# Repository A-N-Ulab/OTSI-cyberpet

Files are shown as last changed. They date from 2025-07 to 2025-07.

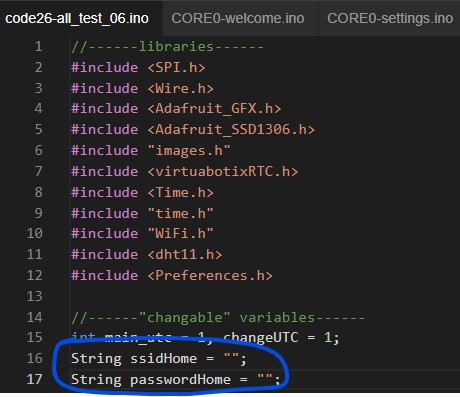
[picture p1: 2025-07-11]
instructions/change wifi.jpg

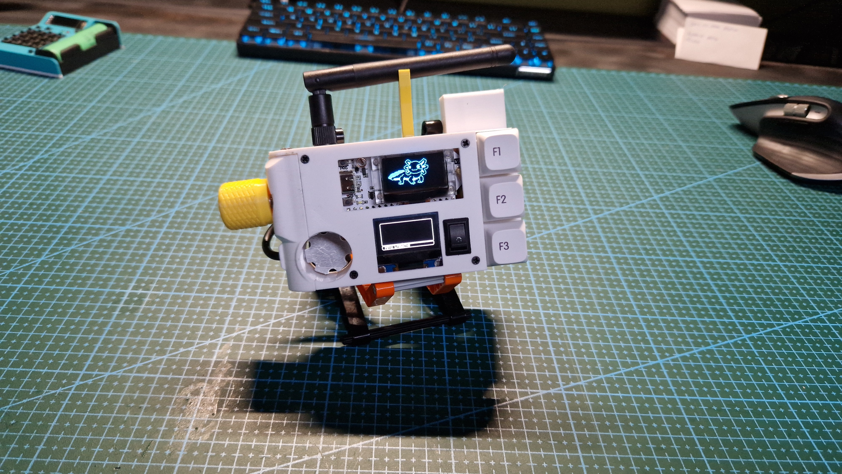
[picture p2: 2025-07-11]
photos/20240127_144444.jpg

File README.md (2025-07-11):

<p align="center">
  

</p>
<p align="center">
  
  
  
  
  
</p>

<p align="center">
  
  
  

</p>

**<p align="center">Info! This is a reupload of Otsi's repo bc of security stuff</p>**

# About this project
### Story
It all started when [cyberdeck cafe](https://cyberdeck.cafe/) announced a contest for cyberpet based on heltec development board. And fast forward 6 months my cyberpet is ALMOST done.

### Credits
Otsi's graphics are based on axolotl design made by [witch](https://dinopixel.com/pixel-art/purple-axolotl/17015)   
Main menu is based on a desing by [upirr](https://github.com/upiir/arduino_oled_menu)   
This project wouldn't be possible without awesome cyberdeck cafe's community. [Cyberdeck cafe website](https://cyberdeck.cafe/), [Cyberdeck cafe discord](https://discord.gg/cyberdeck-cafe-607459933784637460)

### Disclaimers 
* There are a lot of things that can and probably will change, to get latest cad files, code and instructions download lates [release](https://github.com/A-N-Ulab/OTSI-cyberpet/releases/latest)
* soldering otsi is not beginner friendly, have it in mind before you start this project

# Build your own
### Needed items
Detailed information about needed items is in the newest release in pdf called *__list of items needed__*
| Name | Quantity(pieces) | info |
| --- | --- | --- |
| heltec LoRa v3 | 1 | - |
| Mx switch | 3 | i'm using brown ones |
| Antena for lora | 1 | IPX to SMA cable and SMA antena |
| Keycap | 3 | - |
| 18650 battery cell | 1 | - |
| 18650 battery holder | 1 | 76x20x19mm |
| RTC DS1302 | 1 | - |
| CR2032 | 1 | - |
| DHT11 | 1 | temperature and humidity sensor |
| ec11 rotary encoder | 1 | rotary encoder with button |
| Rocker switch | 1 | cutoutsize of 13.5x9mm |
| photo resistor 5-10kohm | 1 | - |
| 3mm LED | 2 | one blue LED and one red LED |
| TP4056 | 1 | with USB C |
| push button | 1 | 6x6mm |
| USB C cable| 1 | USB A to USB C|
| 1W led | 1 | max heatsink diameter 20mm |
| I2C 0.96inch OLED | 1 | - |
| 10k resistor | 5 | - |
| M2 threaded inserts | 6 | - |
| M2x8mm screws | 6 | - |

### Case
Theoretically you could design your own case but I'm providing my case design. There are 5 stl's:  
* Antena holder - print without supports
* Knob - print without supports
* Cover - pritn with supports
* Two Main body files, one with holes for m2 threded inserts one with holes just for screws - both are print without supports    
Additionaly there are 2 files (.f3d and .step) that contain whole Otsi design

### Schematic and soldering
More accurate schematic is avaiable in latest release in pdf called *__schematic__*  
schematic image
Solder everything according to the schematic provided, for additional help in latest release there is a pdf file named *__photos__* that have, as name sugests, all the photos from my soldering process.

### Software
Before uploading otsi's code you are going to have
to change 2 variables:    
     
Set those two variables to WiFi network (ssid and password) that you always want to connect to, your *__home wifi__*     
After that you are ready to upload code to your heltec or from now your own Otsi cyberpet   

### Usage
To go to main many or chose any option press enoder's button, button number 3 is a return, everything else will be descibed on otsi itself.  
To charge Otsi use port on the top. To program Otsi use USB cable.  
NEVER PLUG IN OTSI TO USB WHEN POWER SWITCH IS TURNED ON

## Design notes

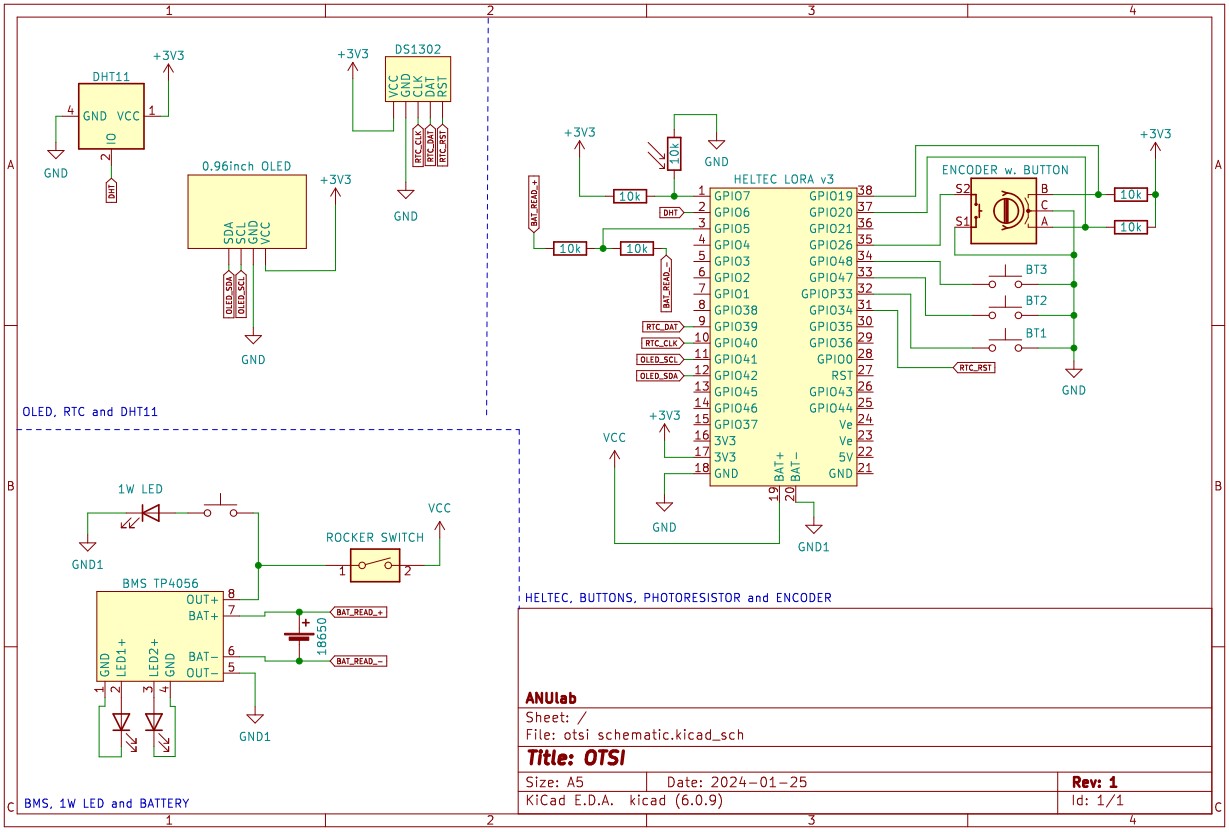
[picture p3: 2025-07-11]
instructions/schematic image .jpg

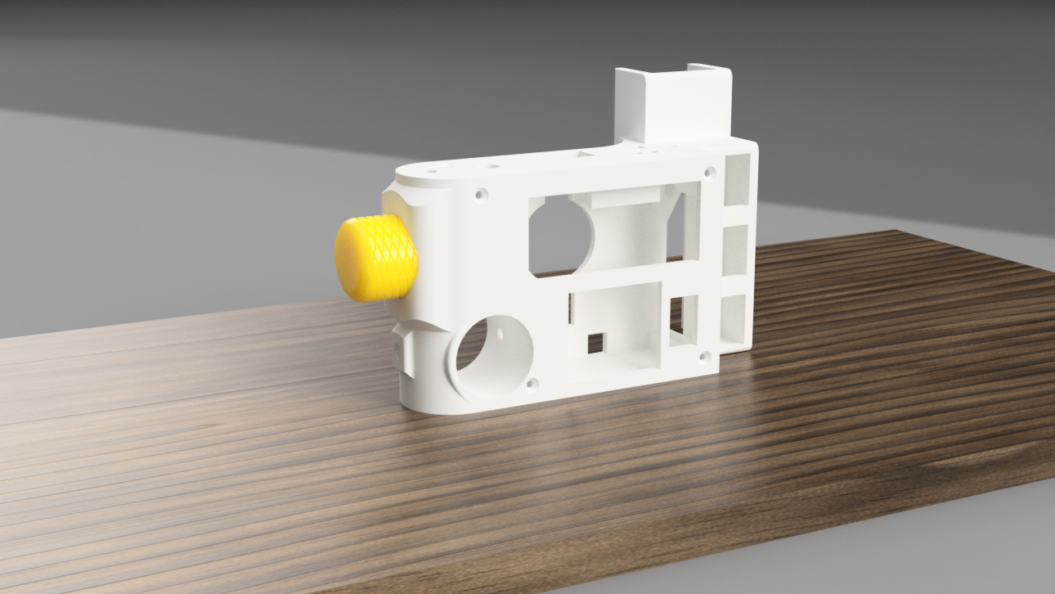
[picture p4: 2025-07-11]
photos/received_341719275412142.png

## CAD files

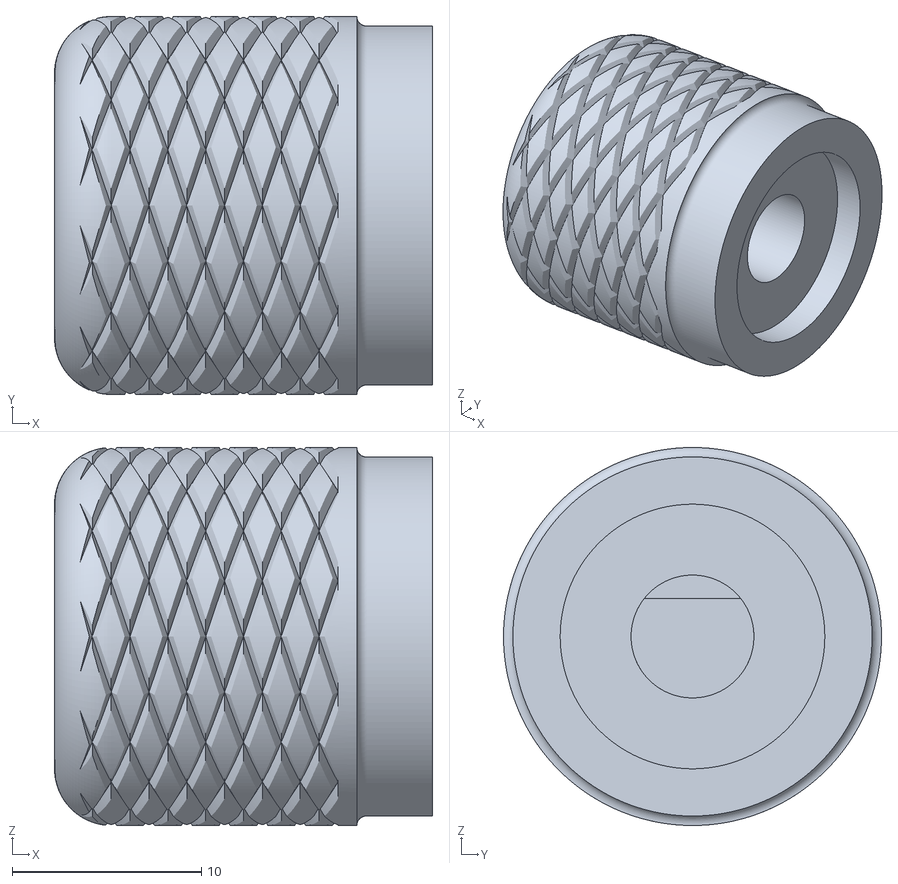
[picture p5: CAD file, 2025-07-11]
cad files/new cad files - Otsi rev2/knob v2.2.stl
20.0 x 20.0 x 20.0

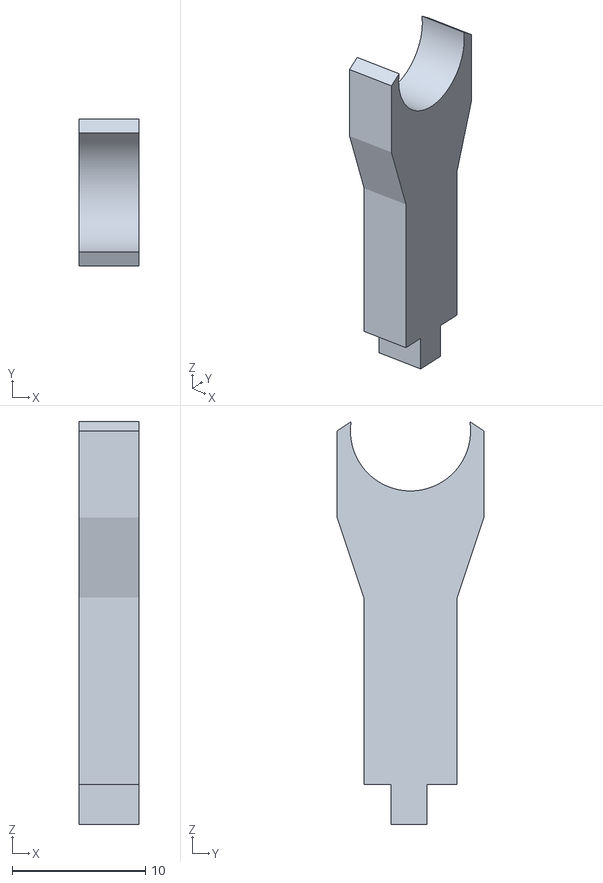
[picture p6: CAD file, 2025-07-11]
cad files/new cad files - Otsi rev2/antena holder v1.3.stl
4.50 x 11.0 x 30.2

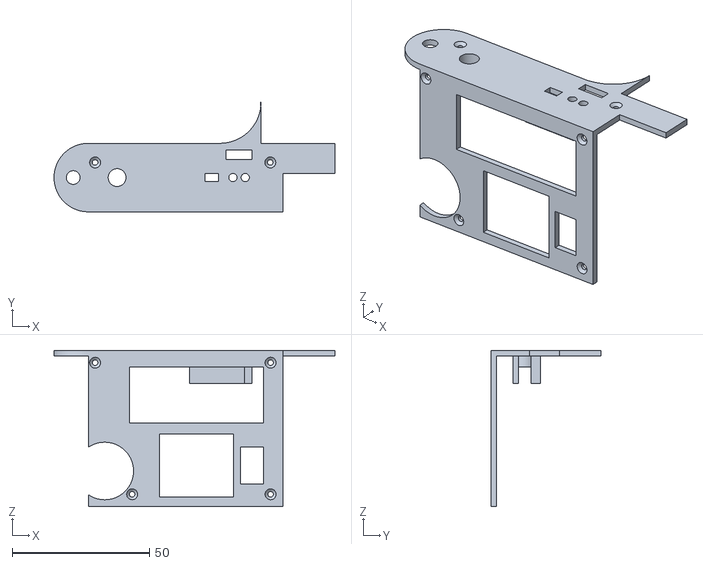
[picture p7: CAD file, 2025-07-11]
cad files/new cad files - Otsi rev2/cover v2.2.stl
102.5 x 40.0 x 57.0

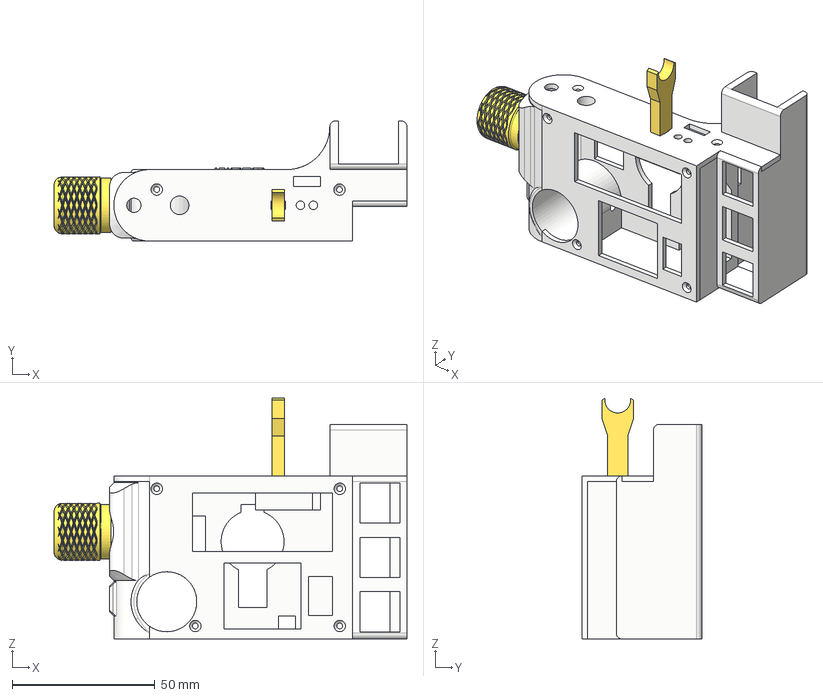
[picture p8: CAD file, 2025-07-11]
cad files/new cad files - Otsi rev2/otsi 25012024.step
123.4 x 42.0 x 84.2 mm
knob
cover
antena holder

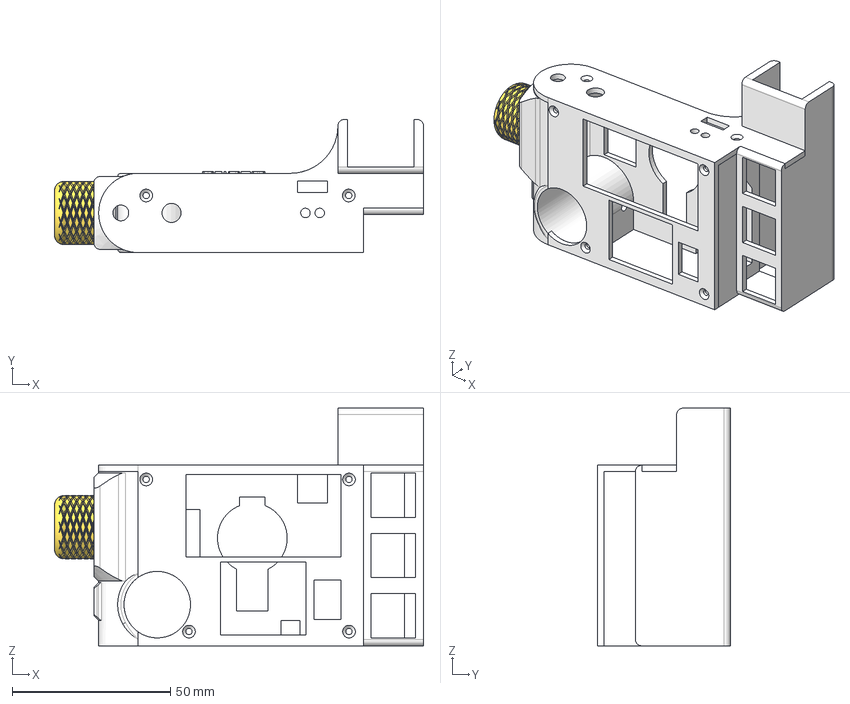
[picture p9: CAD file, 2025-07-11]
cad files/new cad files - Otsi rev2/otsi 13012024.step
116.4 x 42.0 x 75.0 mm
knob

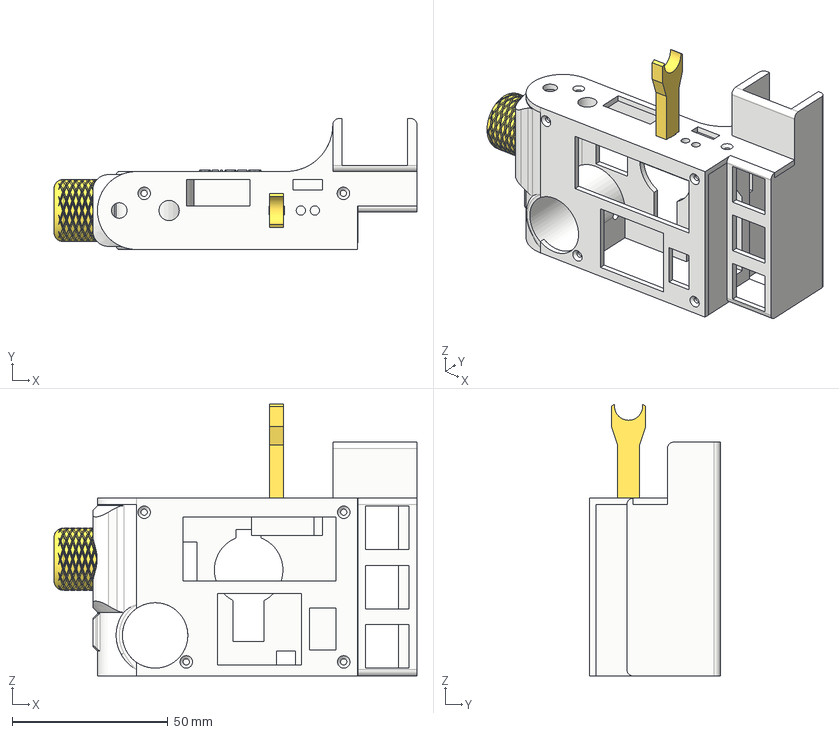
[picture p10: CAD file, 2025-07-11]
cad files/new cad files - Otsi rev2/otsi 16012024.step
116.4 x 42.0 x 87.2 mm
knob
cover
antena holder

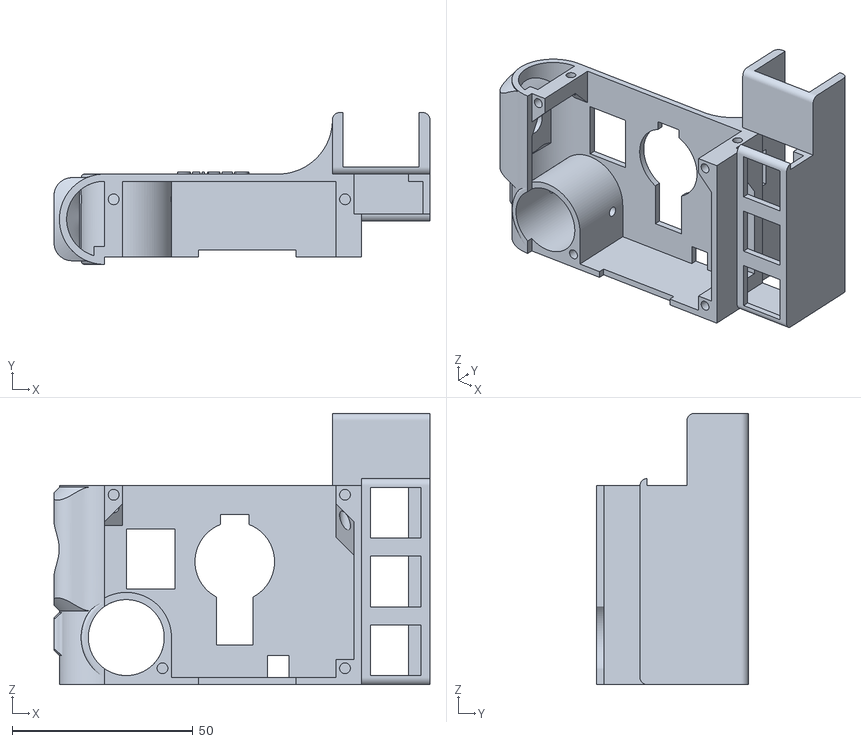
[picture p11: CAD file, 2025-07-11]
cad files/new cad files - Otsi rev2/body v2.2.stl
104.0 x 42.0 x 75.0

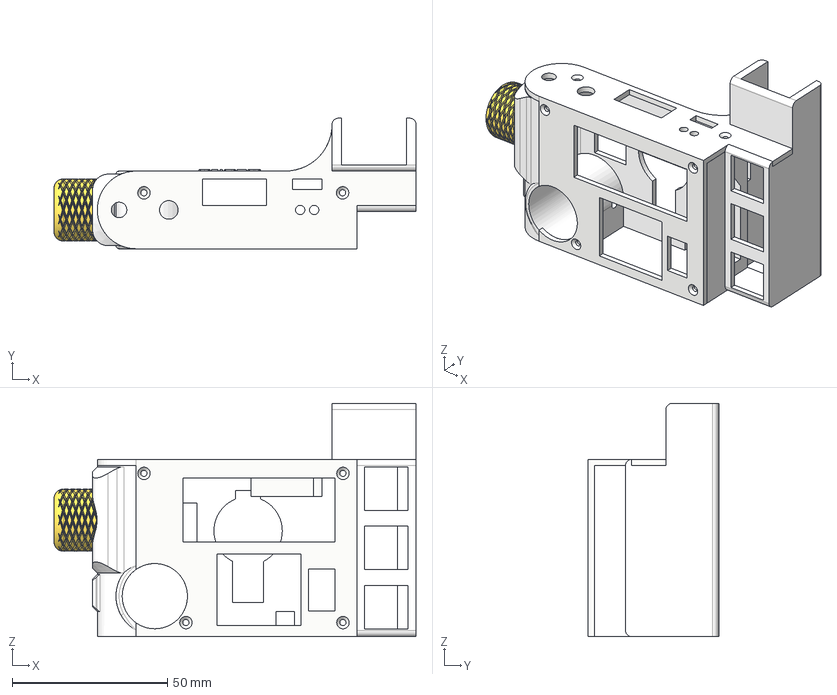
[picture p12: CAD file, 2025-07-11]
cad files/new cad files - Otsi rev2/otsi 15012024.step
116.4 x 42.0 x 75.0 mm
knob
cover

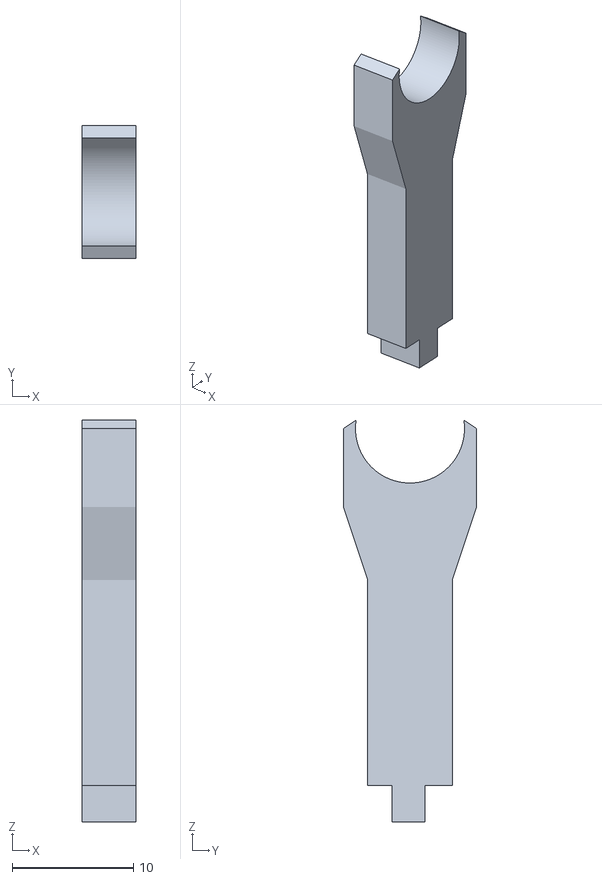
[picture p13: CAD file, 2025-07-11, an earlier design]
cad files/new cad files - Otsi rev2/antena holder v1.1.stl
4.50 x 11.0 x 33.2

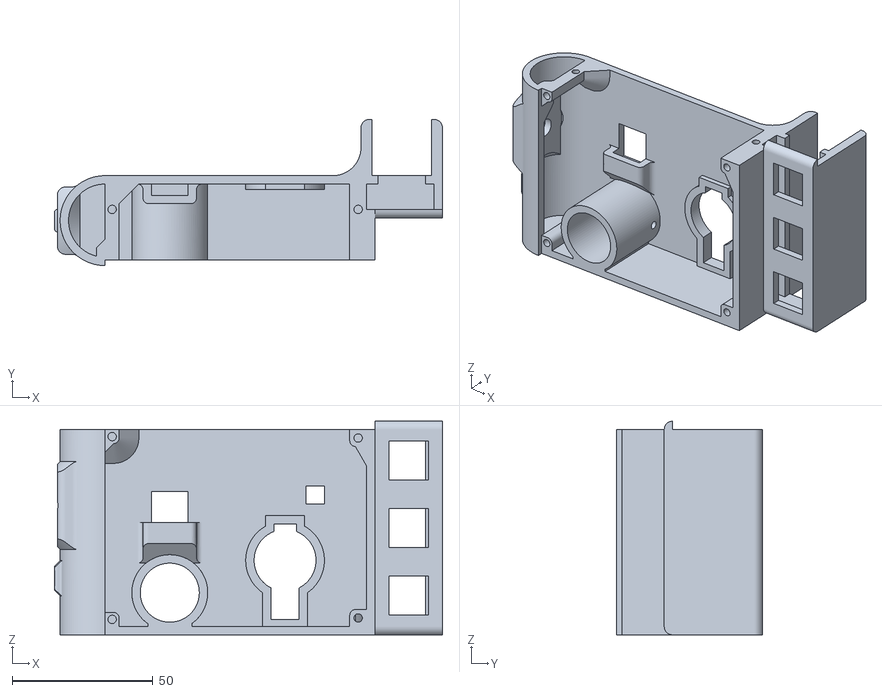
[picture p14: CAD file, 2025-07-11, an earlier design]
cad files/old cad files - Otsi rev1/body v2.stl
138.0 x 52.0 x 76.0

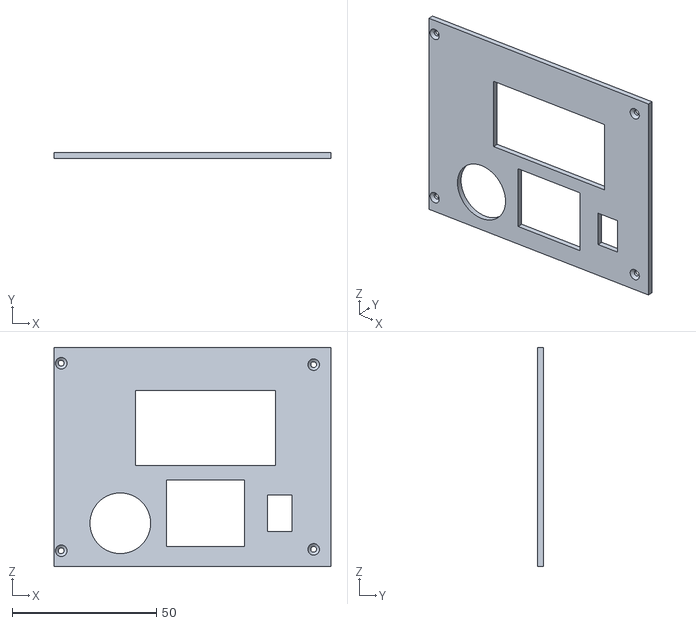
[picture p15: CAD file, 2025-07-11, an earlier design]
cad files/old cad files - Otsi rev1/cover v1.stl
96.0 x 2.00 x 76.0

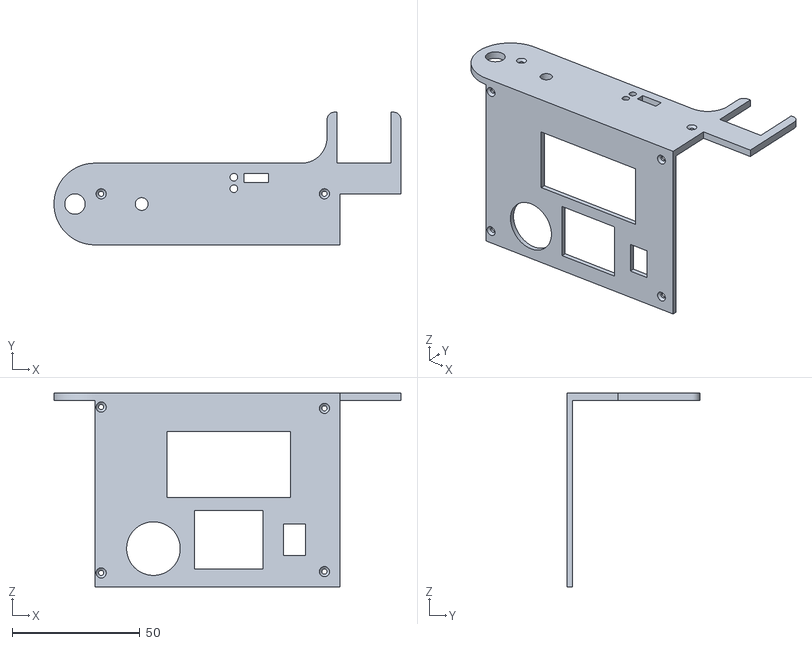
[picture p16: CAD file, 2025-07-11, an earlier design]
cad files/old cad files - Otsi rev1/cover v2.stl
136.0 x 52.0 x 76.0

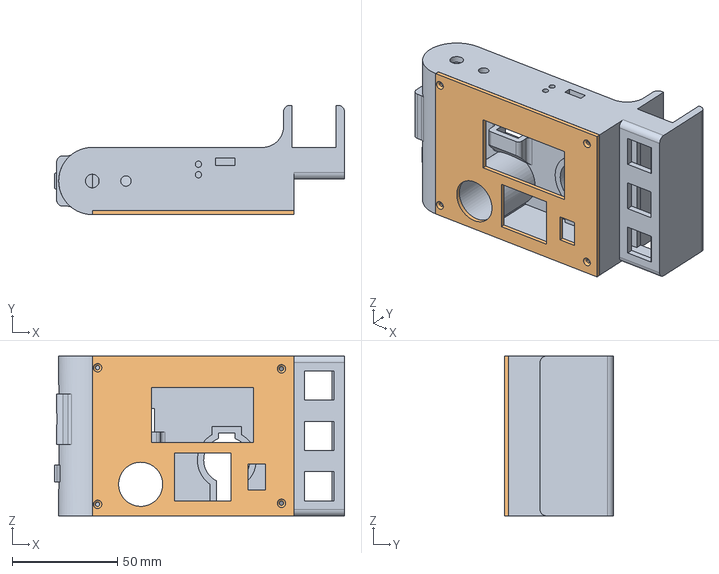
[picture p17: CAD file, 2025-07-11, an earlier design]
cad files/old cad files - Otsi rev1/otsi 10012024.step
138.0 x 52.0 x 76.0 mm

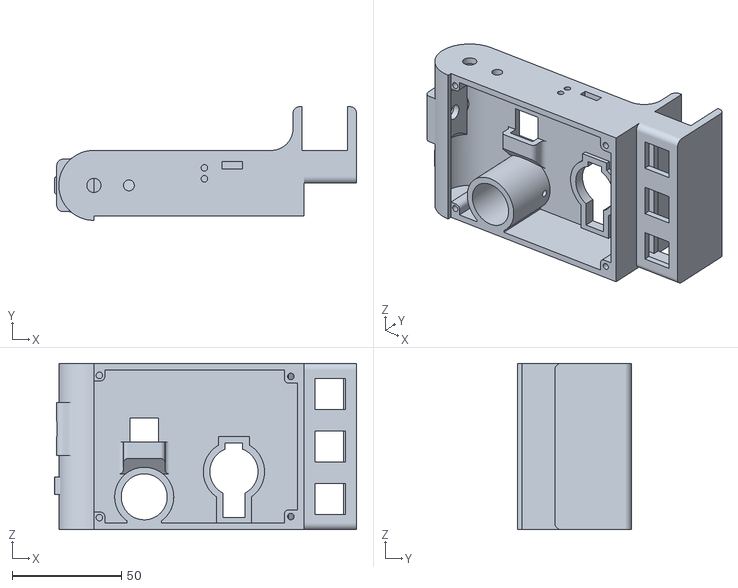
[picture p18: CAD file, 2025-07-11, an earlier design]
cad files/old cad files - Otsi rev1/body v1.stl
138.0 x 52.0 x 76.0

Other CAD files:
cad files/new cad files - Otsi rev2/otsi 24012024.step
cad files/new cad files - Otsi rev2/body v2.3 - inserts.stl
cad files/new cad files - Otsi rev2/body v2.3 - no inserts.stl
cad files/new cad files - Otsi rev2/body v1.stl
cad files/new cad files - Otsi rev2/antena holder v1.2.stl
cad files/new cad files - Otsi rev2/antena holder v1.stl
cad files/new cad files - Otsi rev2/body v2.1.stl
cad files/new cad files - Otsi rev2/body v2.stl
cad files/new cad files - Otsi rev2/cover v1.stl
cad files/new cad files - Otsi rev2/cover v2.1.stl
cad files/new cad files - Otsi rev2/cover v2.stl
cad files/new cad files - Otsi rev2/knob v1.1.stl
cad files/new cad files - Otsi rev2/knob v1.stl
cad files/new cad files - Otsi rev2/knob v2.1.stl
cad files/new cad files - Otsi rev2/knob v2.stl
cad files/new cad files - Otsi rev2/otsi 13012024.f3d
cad files/new cad files - Otsi rev2/otsi 15012024.f3d
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

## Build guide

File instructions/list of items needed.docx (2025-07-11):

NAME | QUANTITY (pieces) | REFERENCE LINK | REFERENCE IMAGE

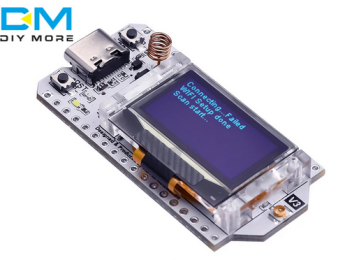
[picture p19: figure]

Heltec LoRa v3 | 1 | https://pl.aliexpress.com/item/1005004993408849.html

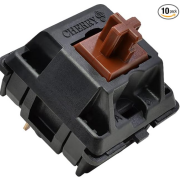
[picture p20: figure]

Mx switch (I’m using brown ones) | 3 | pack of 10: https://www.amazon.com/Original-Cherry-Switches-Mechanical-Keyboard/dp/B09J3GR5WD?th=1

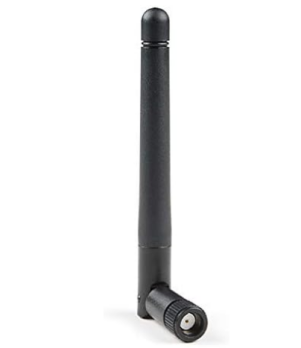
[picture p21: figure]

Antena and cable for LoRa REMEMBER TO ORDER THE RIGHT FREQUENCY FOR YOUR LORA | 1 | https://www.amazon.com/915MHz-LoRa-Antenna-RP-SMA-Wave/dp/B07HZ3BSHM/

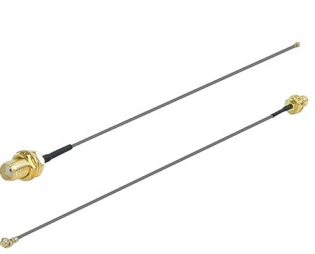
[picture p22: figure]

| 1 | Pack of 2: https://www.amazon.com/Proxicast-Low-Loss-Coaxial-Bluetooth-Antennas/dp/B09GJGNPQX/

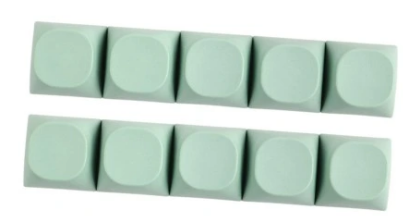
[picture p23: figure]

Keycap Best with numbers from 1 to 3 | 3 | https://www.amazon.com/SparkFun-Electronics-Cherry-MX-Keycap/dp/B082TMSLNQ/

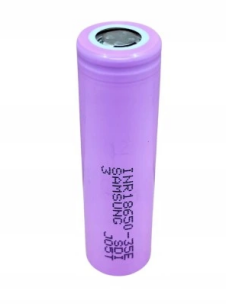
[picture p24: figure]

18650 battery cell | 1 | -

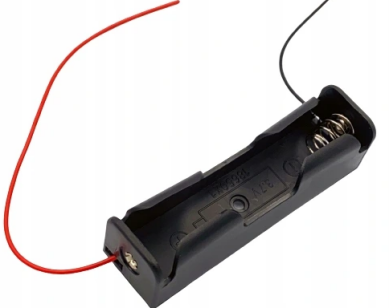
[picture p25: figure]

18650 battery holder | 1 | Pack of 10: https://www.amazon.com/DIANN-10pcs-Battery-Holder-Single/dp/B0BJV7SK5D/

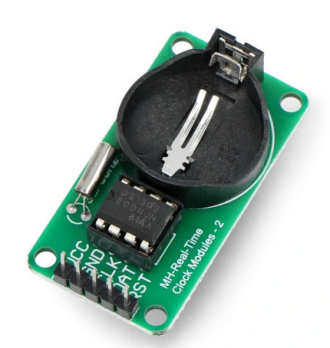
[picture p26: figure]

RTC DS1302 | 1 | https://www.amazon.com/RedTagCanada-DS1302-Module-Real-Time-Arduino/dp/B0CQYC3WJH/

DISCLAIMER:

Links are only for reference and some of them lead to e.g. pack of 20, the real quantity is in a column called the same. If there is quantity of 3 it means that you need 3 pieces e.g. 3 MX switches

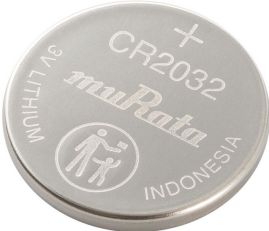
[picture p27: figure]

CR2032 | 1 | https://www.amazon.com/Duracell-Lithium-Battery-Lasting-Count/dp/B07G7KRQQ5/

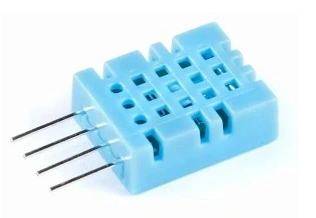
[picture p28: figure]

DHT11 temperature and humidity sensor | 1 | https://www.amazon.com/Micro-Traders-16x12-6x6mm-Temperature-Microcontrollers/dp/B0CMSTP1HS/

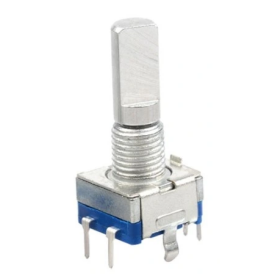
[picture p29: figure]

ec11 rotary encoder with button | 1 | https://www.amazon.com/Bolsen-Rotary-Encoder-Digital-Potentiometer/dp/B07HQD627T/

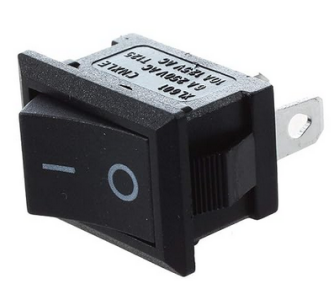
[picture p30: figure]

Rocker switch with cutout size of 13.5x9mm | 1 | https://www.amazon.com/Envistia-Mall-Rocker-Switch-125VAC/dp/B07QFN5Y9K/

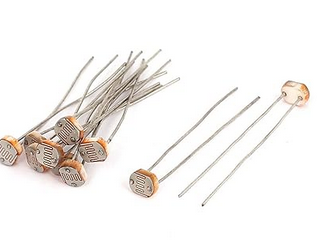
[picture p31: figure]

Photo resistor 5-10kOhm | 1 | https://www.amazon.com/a15071300ux0102-Resistor-Light-Dependent-Photoresistor-Optoresistor/dp/B00Q6ZIK1O

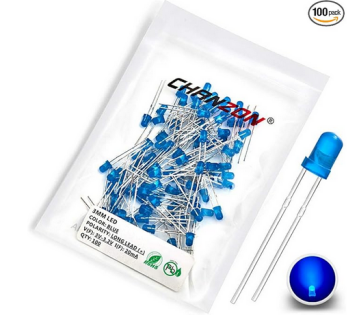
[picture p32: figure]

3mm led | 2 (1 red and 1 blue) | Red, pack of 100: https://www.amazon.com/Diffused-Lighting-Electronics-Components-Emitting/dp/B01C3W6NPS/ Blue, pack of 100: https://www.amazon.com/Diffused-Lighting-Electronics-Components-Emitting/dp/B01C3ZZT6O/

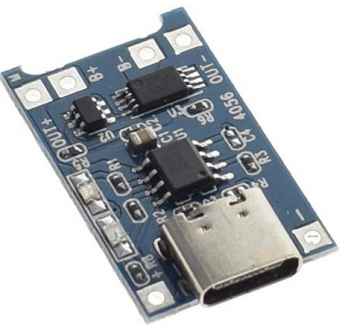
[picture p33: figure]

TP4056 | 1 | Pack of 3: https://www.amazon.com/HiLetgo-Lithium-Charging-Protection-Functions/dp/B07PKND8KG/

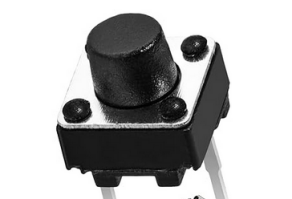
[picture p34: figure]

6x6mm push button | 1 | Pack of 20: https://www.amazon.com/Momentary-Terminal-Pushbutton-Breadboard-Electronic/dp/B09R3ZPWJ7/

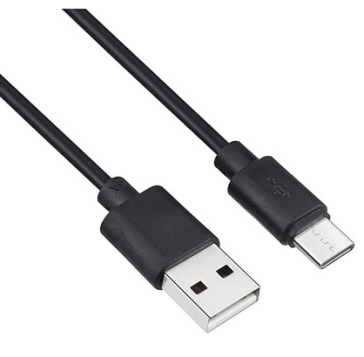
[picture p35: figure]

USB C cable (nothing too fancy, you are gonna cut it anyway) | 1 | https://www.amazon.com/PowerHOOD-Charging-Compatible-Ingenico-MOB55BBBAB-128/dp/B0C8W41D6S/

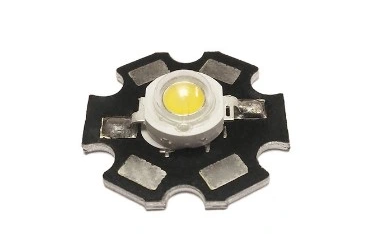
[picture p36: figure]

1W/3W led with max diameter of heatsink: 20mm | 1 | https://www.amazon.com/Light-Beads-Bright-Floodlight-5W-Warm/dp/B097S1RG9G/

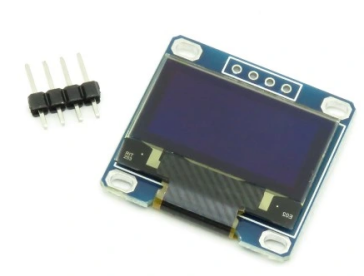
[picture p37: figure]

I2C 0.96 inch OLED display | 1 | Pack of 5: https://www.amazon.com/Hosyond-Display-Self-Luminous-Compatible-Raspberry/dp/B09C5K91H7/

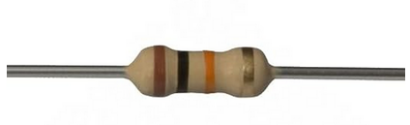
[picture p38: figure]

10k resistor | 5 | Pack of 100: https://www.amazon.com/Projects-100EP51210K0-10k-Resistors-Pack/dp/B0185FIOTA

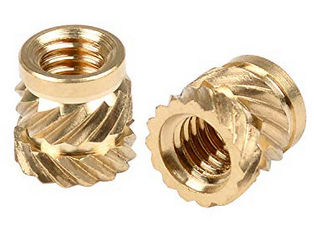
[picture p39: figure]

M2 Threaded inserts | 6 | Pack of 100: https://www.amazon.com/M2x4-0mm-OD3-6mm-Staking-Threaded-Inserts/dp/B08T7NDPQC
M2x5mm screws | 6 | Pack of 10: https://www.amazon.com/Deal4GO-10-Pack-Replacement-Phillips-Nickel/dp/B0B3751BM1/

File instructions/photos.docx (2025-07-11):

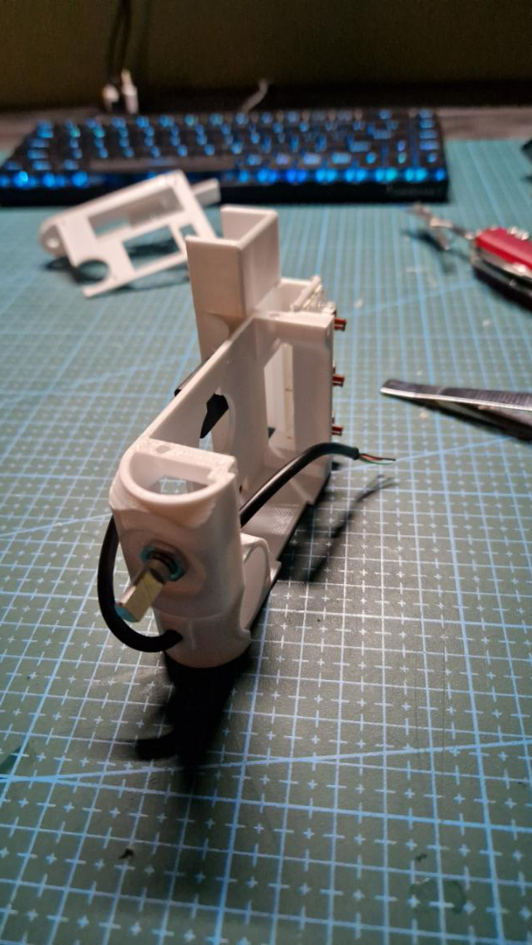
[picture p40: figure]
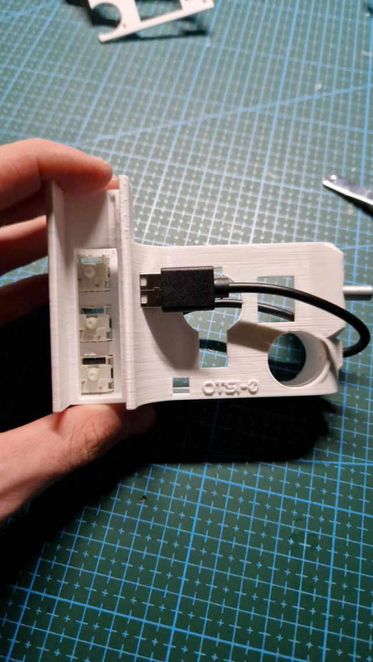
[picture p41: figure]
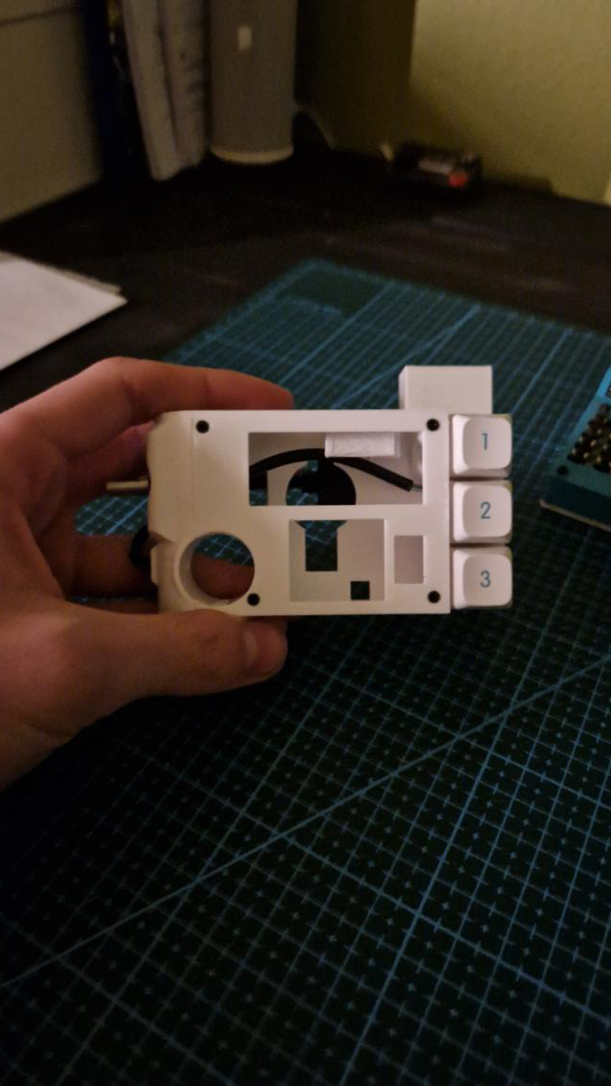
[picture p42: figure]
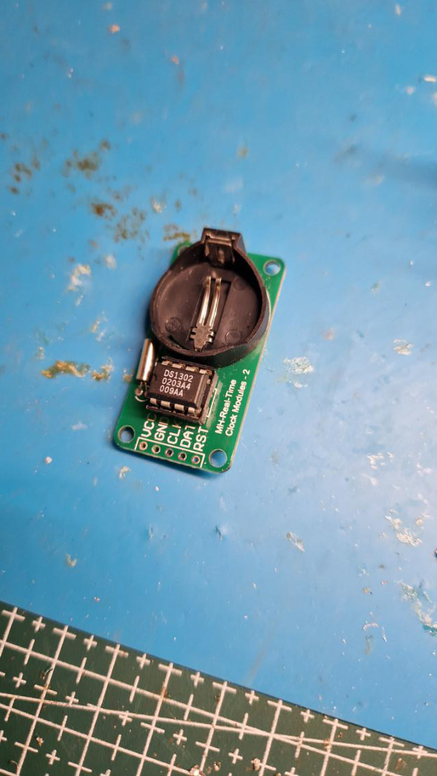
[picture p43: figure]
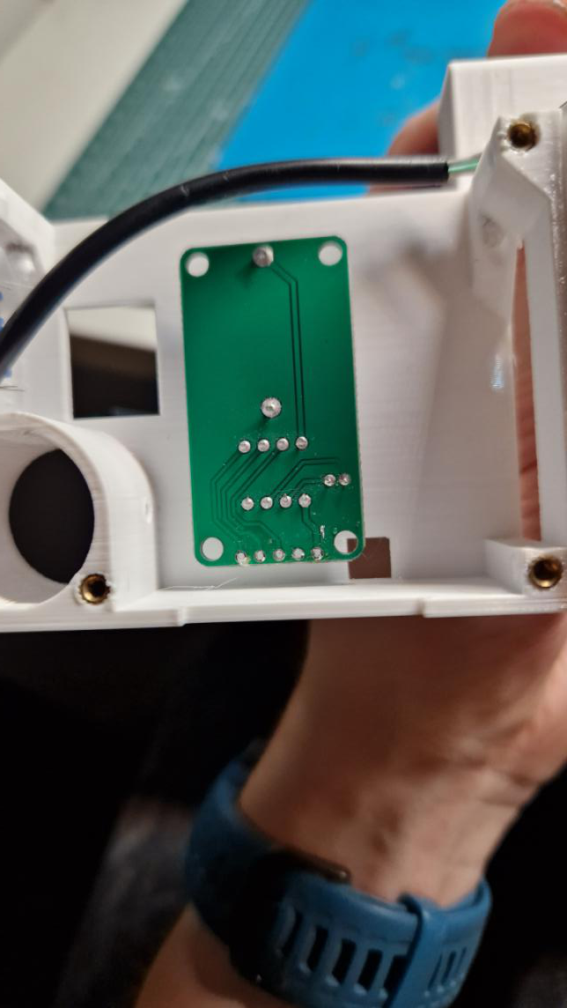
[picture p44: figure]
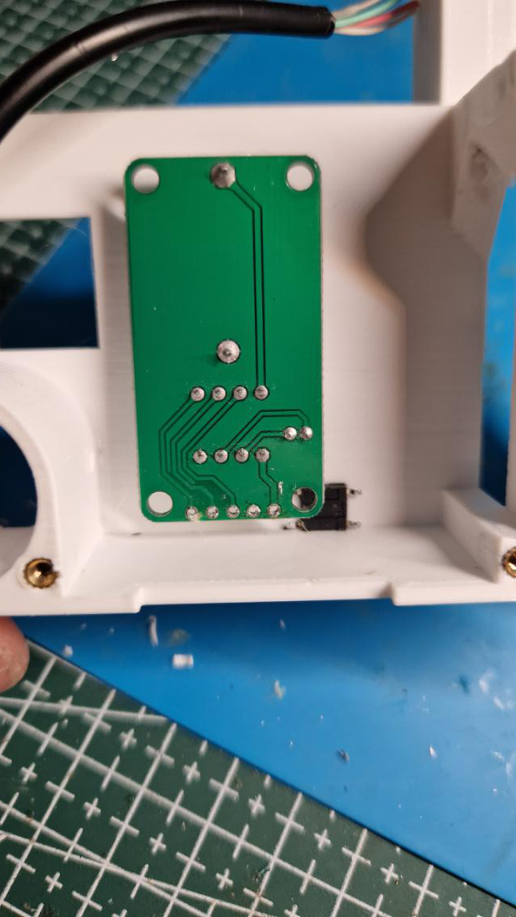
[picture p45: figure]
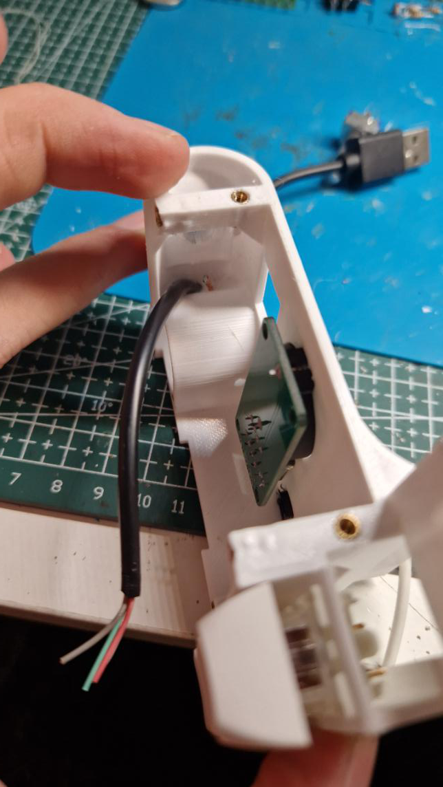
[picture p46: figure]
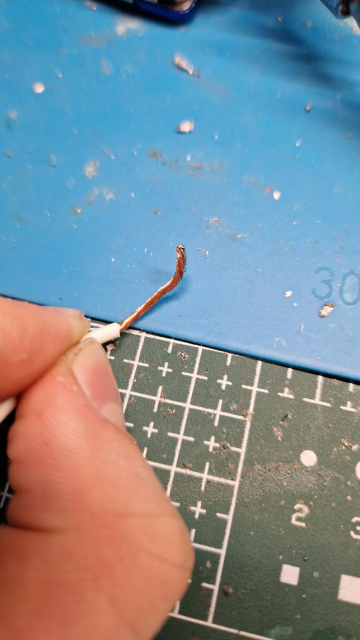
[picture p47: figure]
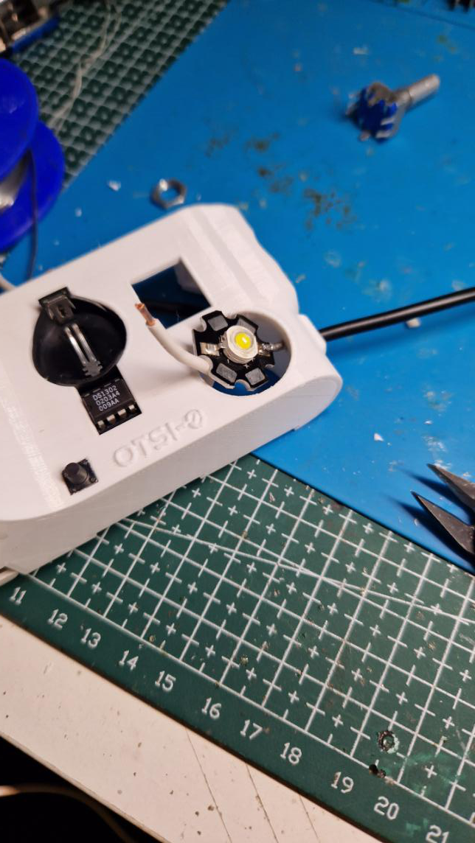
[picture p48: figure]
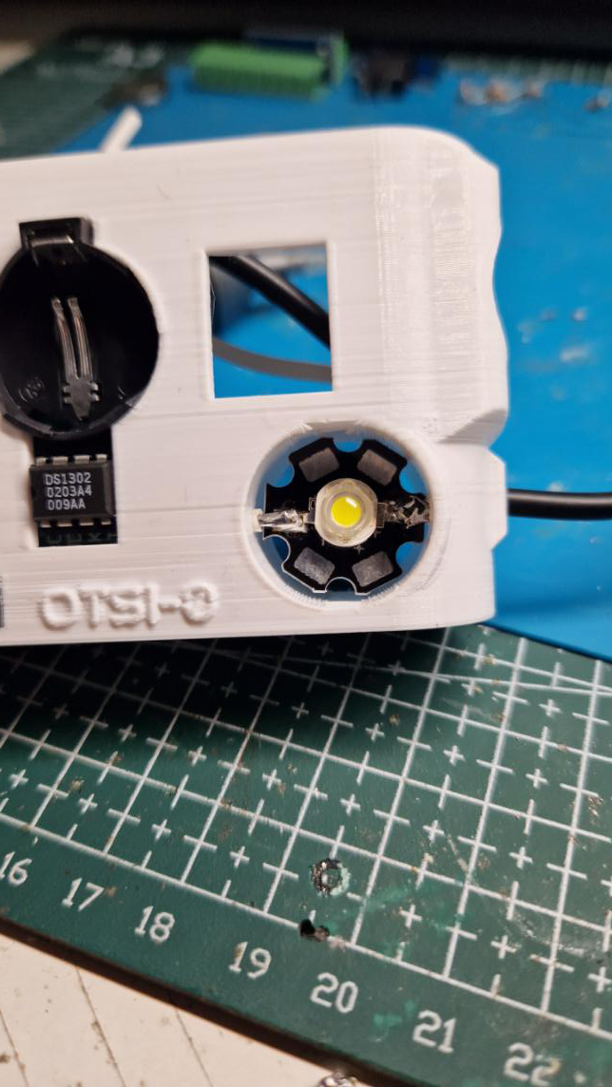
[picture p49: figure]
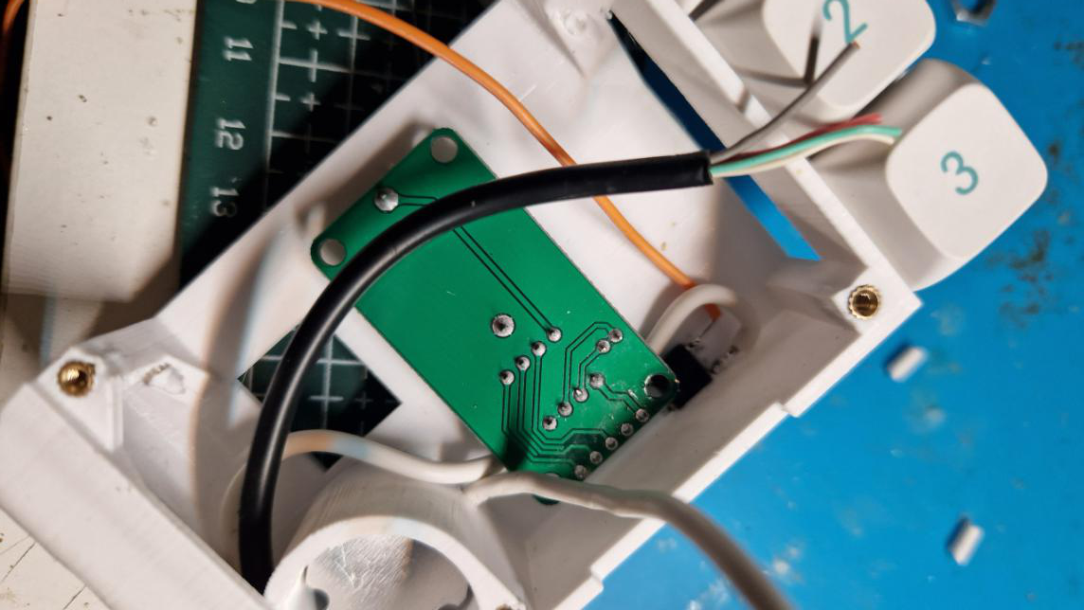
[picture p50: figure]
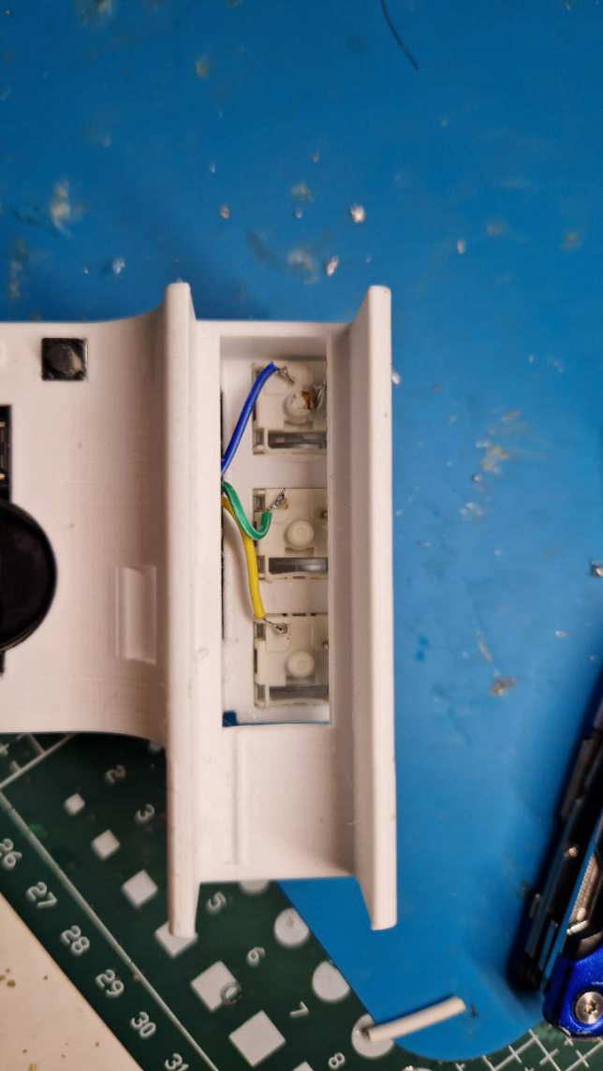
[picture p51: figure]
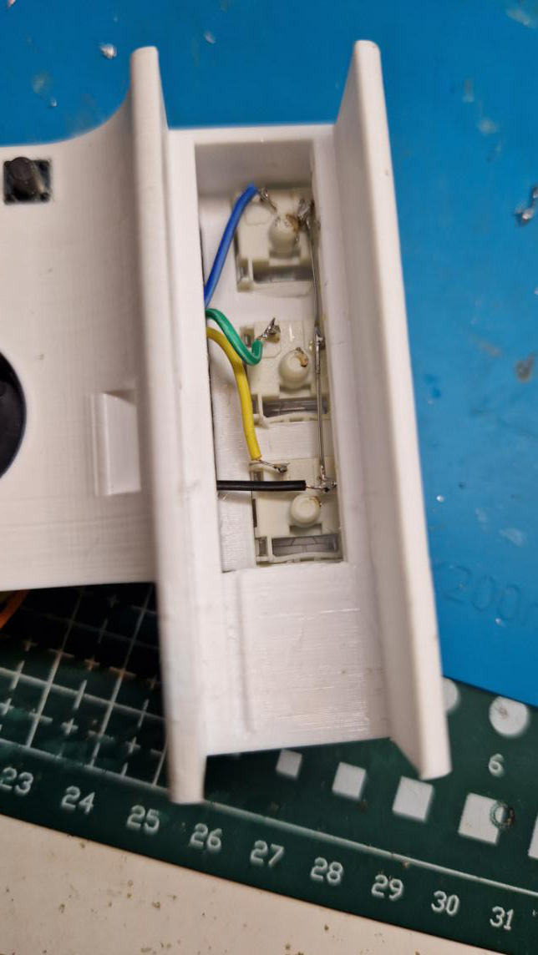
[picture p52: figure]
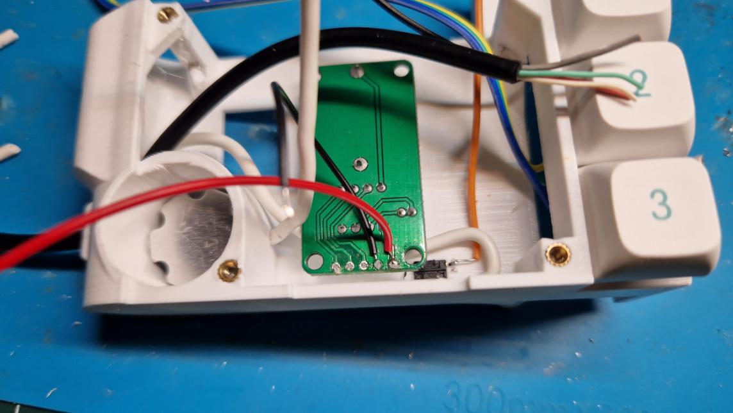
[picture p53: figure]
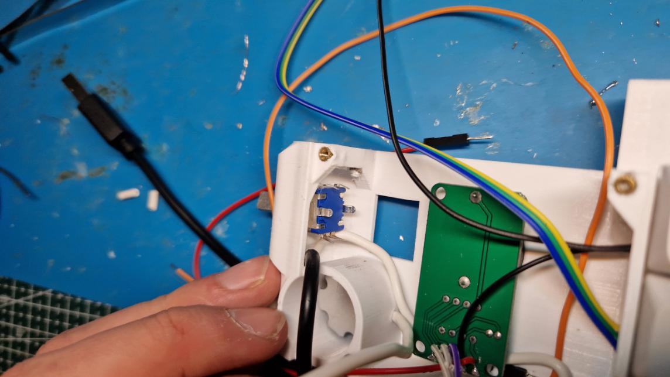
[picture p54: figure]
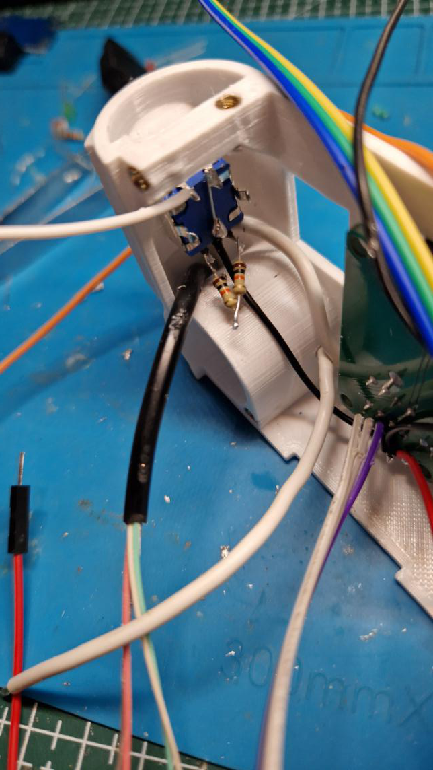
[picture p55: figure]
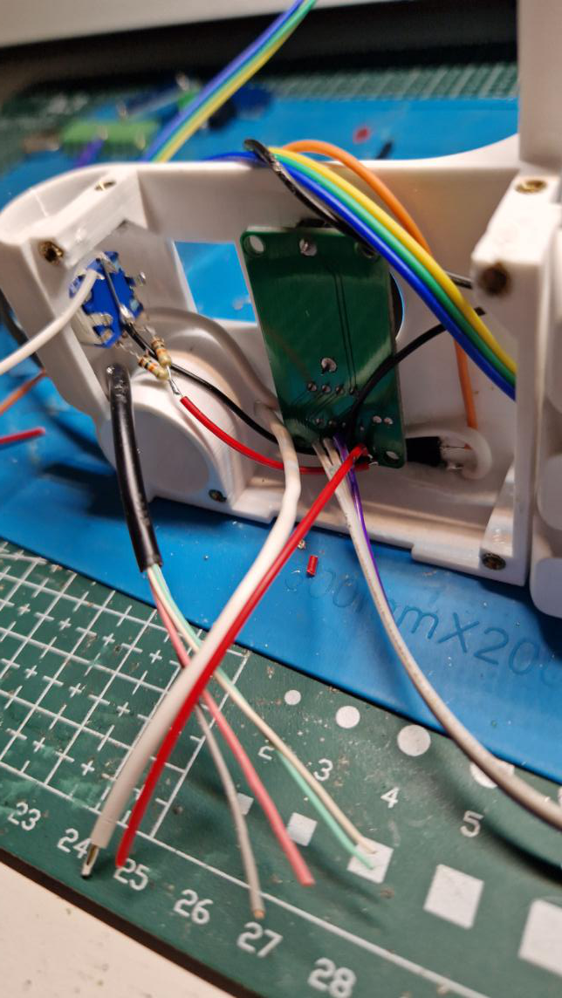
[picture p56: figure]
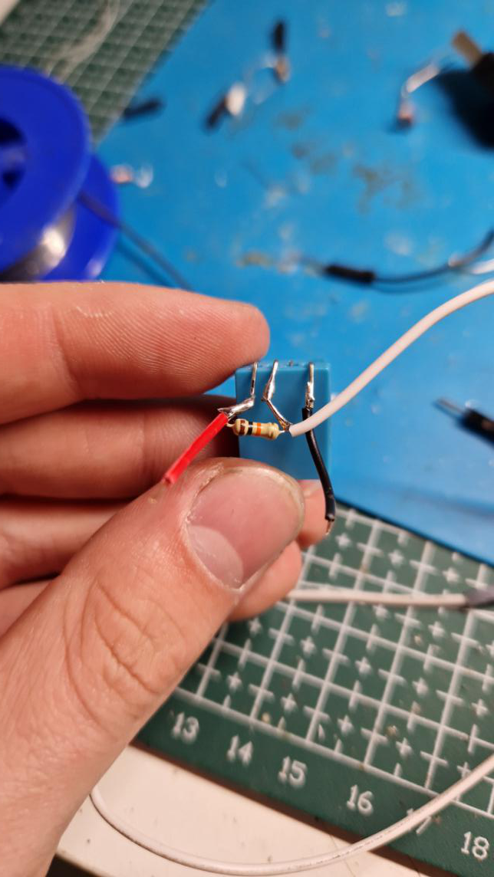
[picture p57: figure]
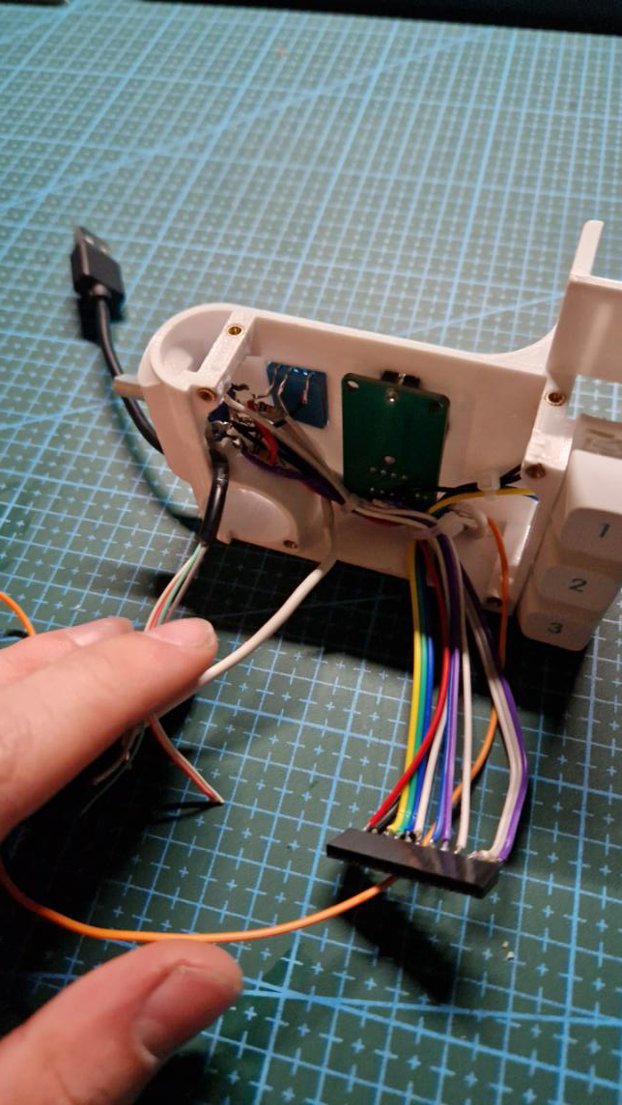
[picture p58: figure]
20231230_151600-cut

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
- cathode

- cathode

+ anode

34

33

32

37

36

35

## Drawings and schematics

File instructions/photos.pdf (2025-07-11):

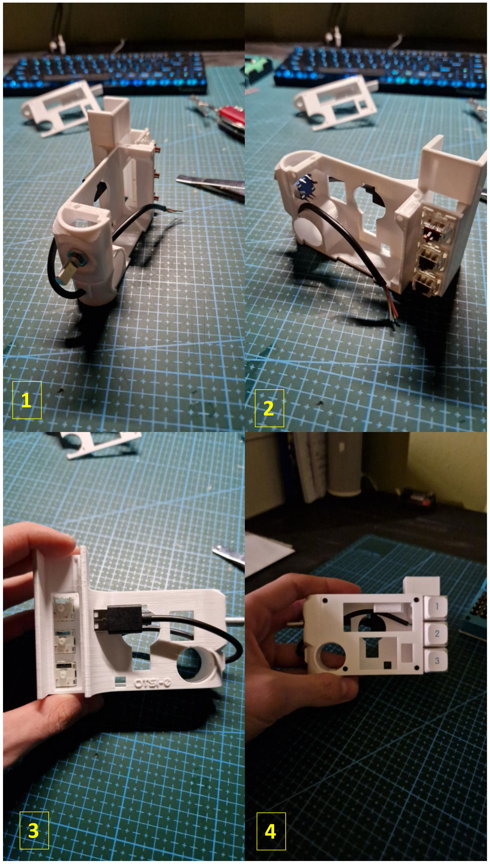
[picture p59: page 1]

1 2

3 4

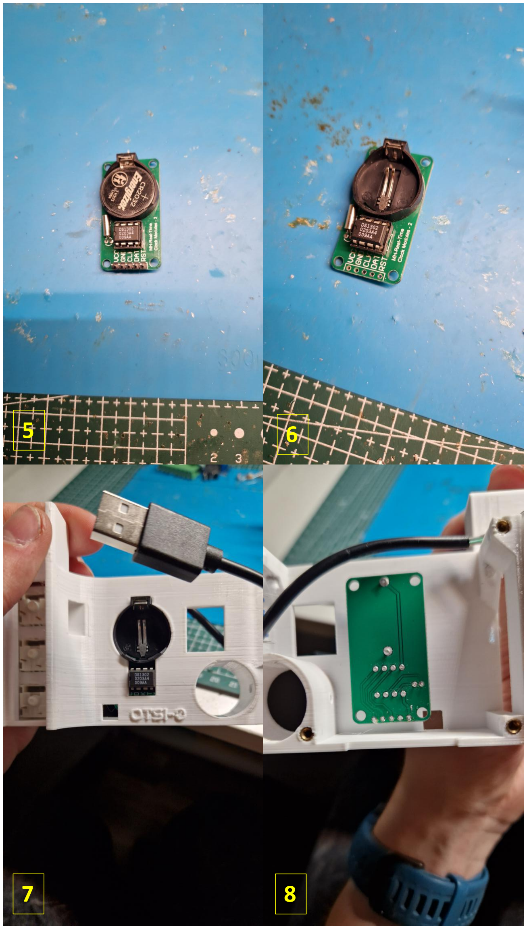
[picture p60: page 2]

5 6

7 8

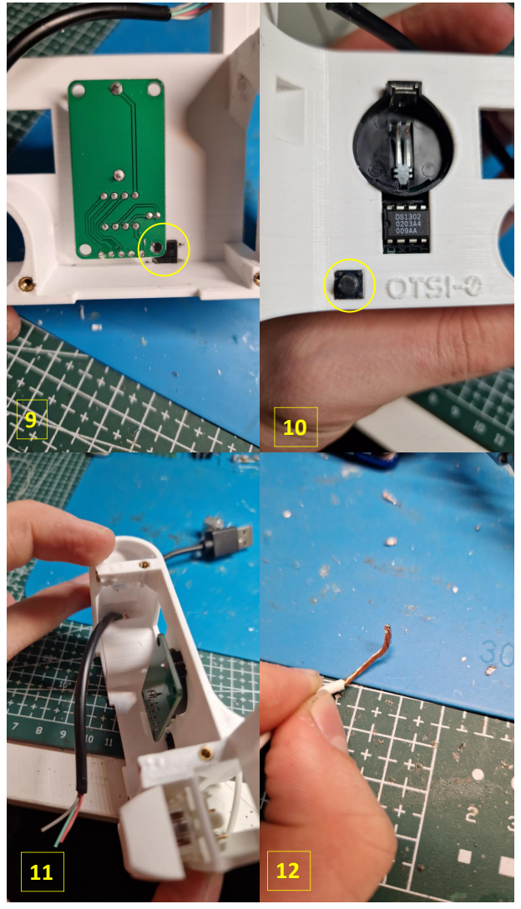
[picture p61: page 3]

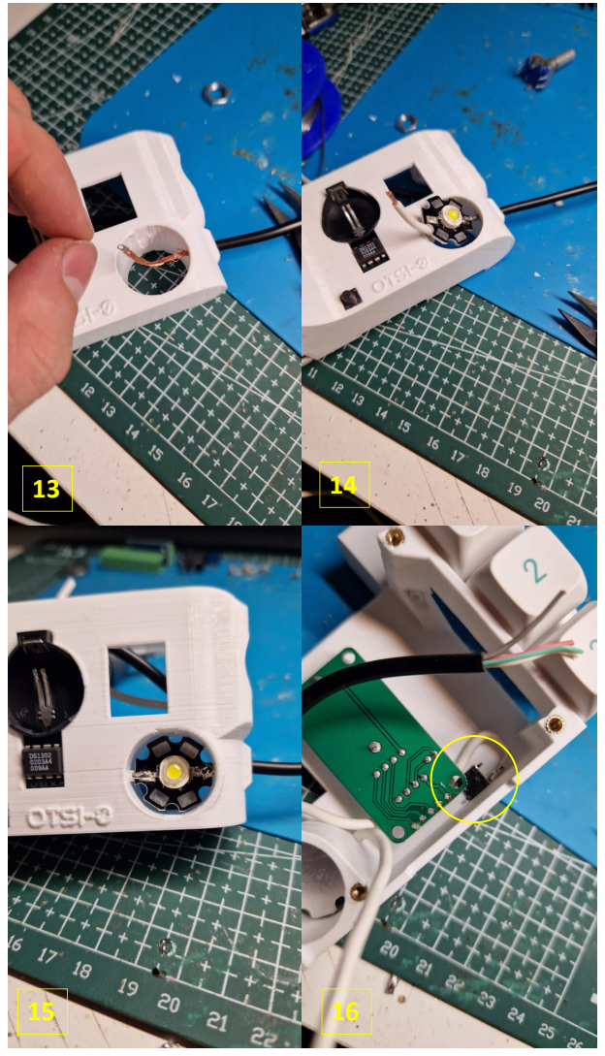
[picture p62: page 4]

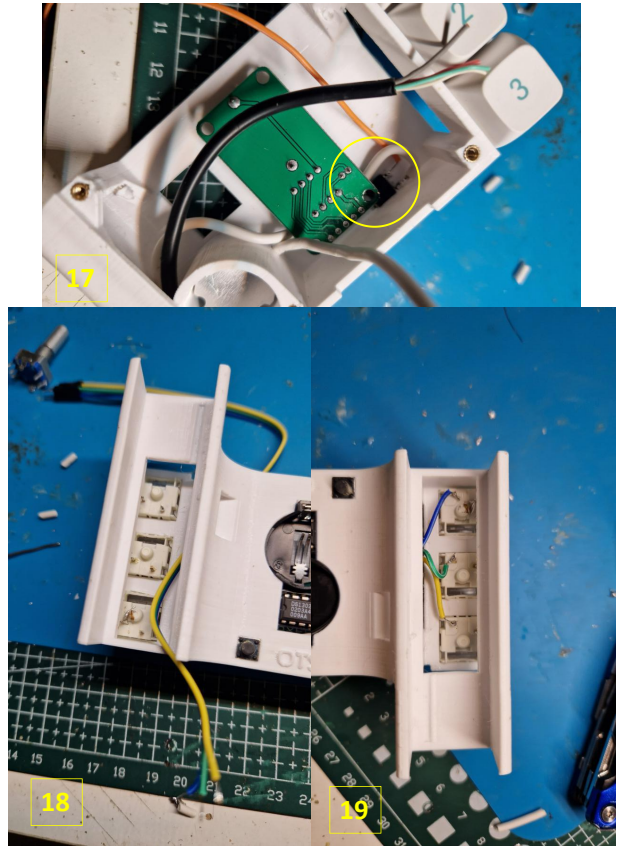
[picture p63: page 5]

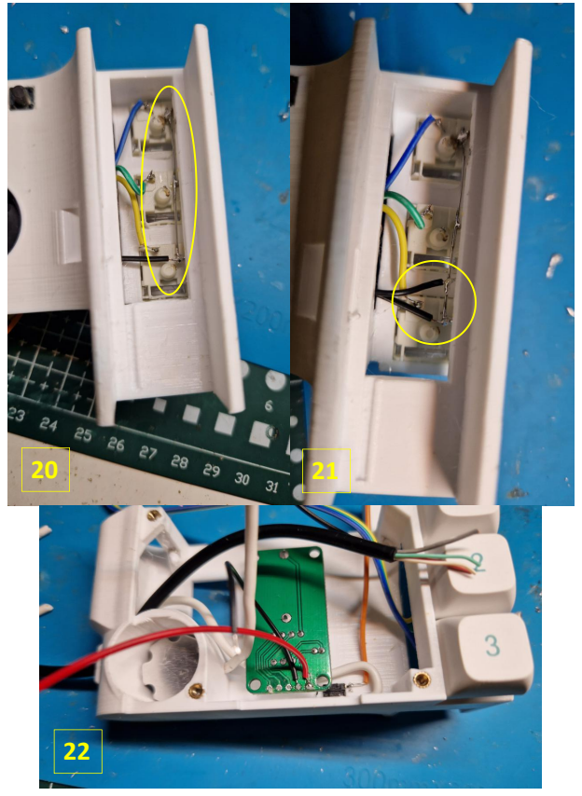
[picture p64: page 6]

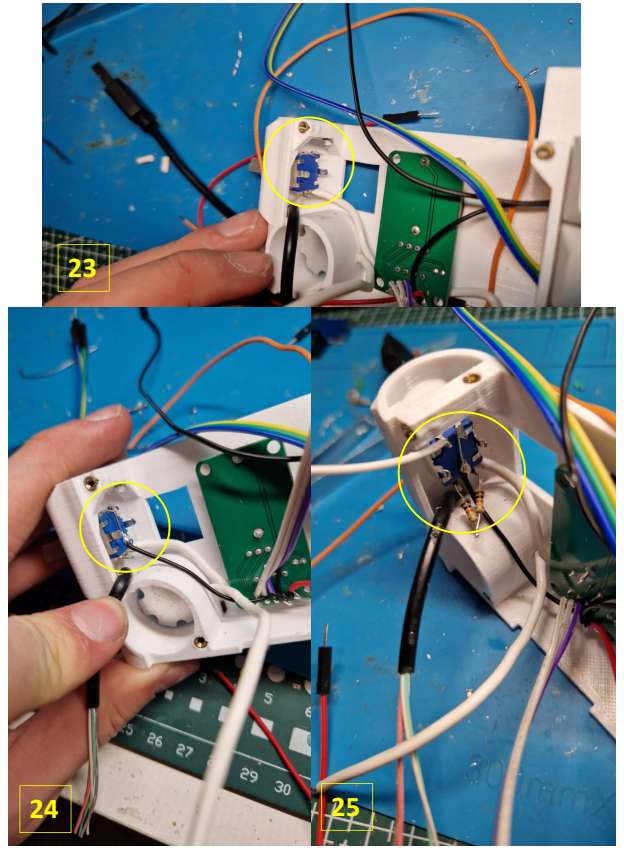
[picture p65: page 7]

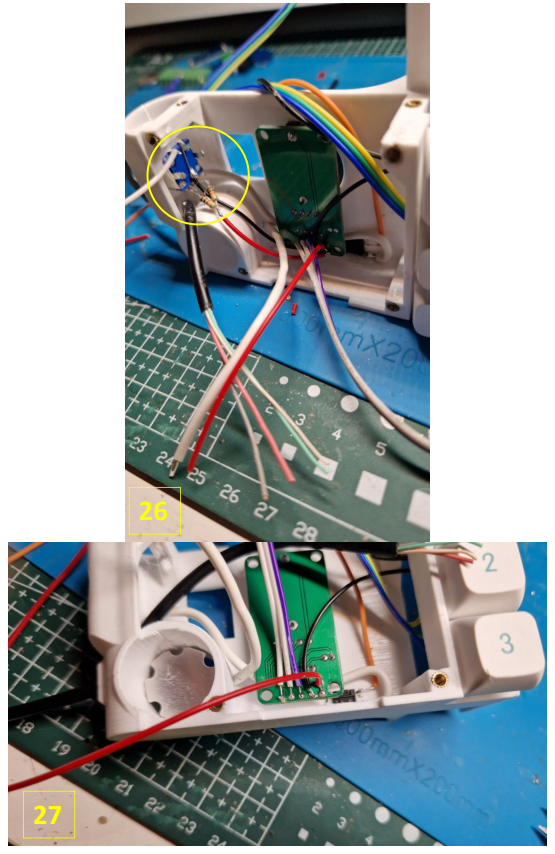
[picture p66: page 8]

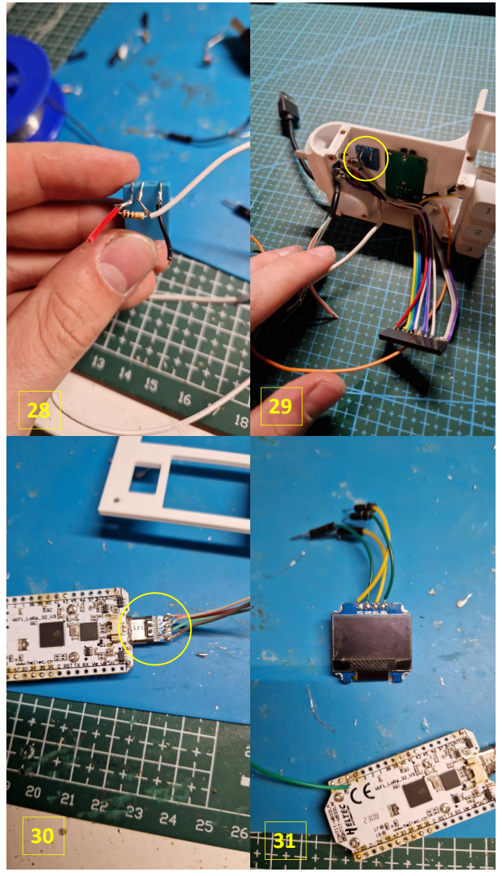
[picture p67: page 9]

### - cathode

### + anode

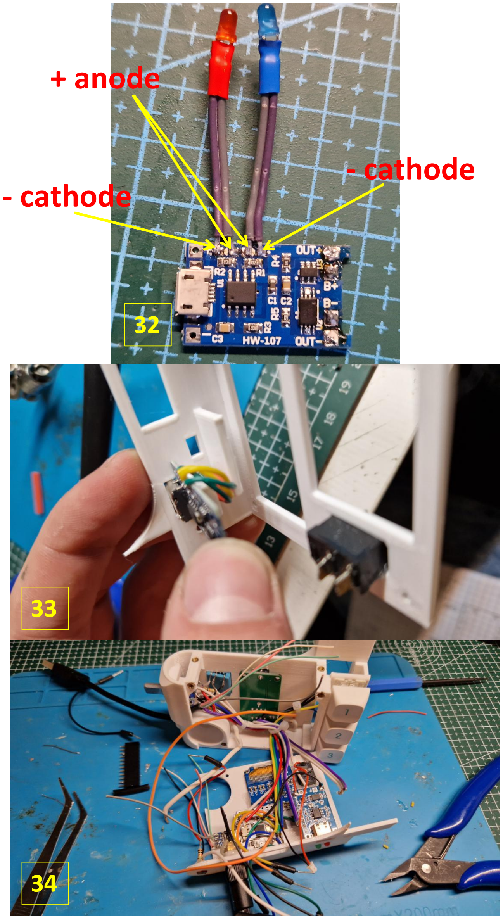
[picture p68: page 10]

### - cathode

32

33

34

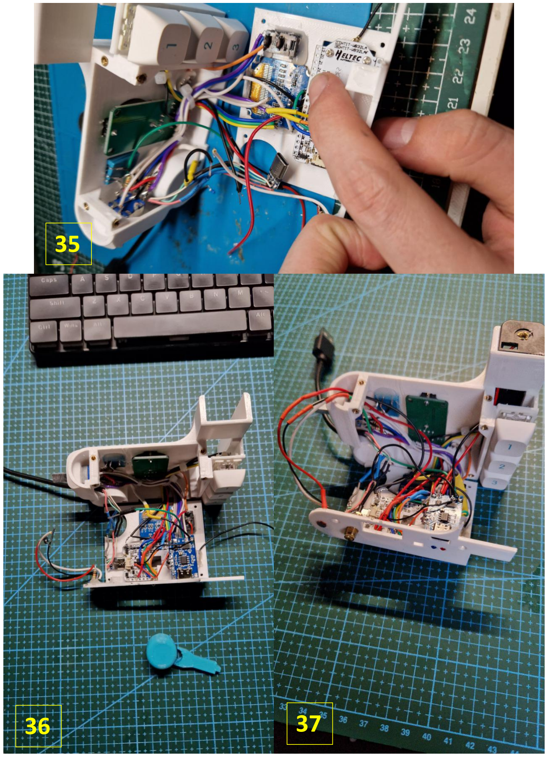
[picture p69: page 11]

35

36 37

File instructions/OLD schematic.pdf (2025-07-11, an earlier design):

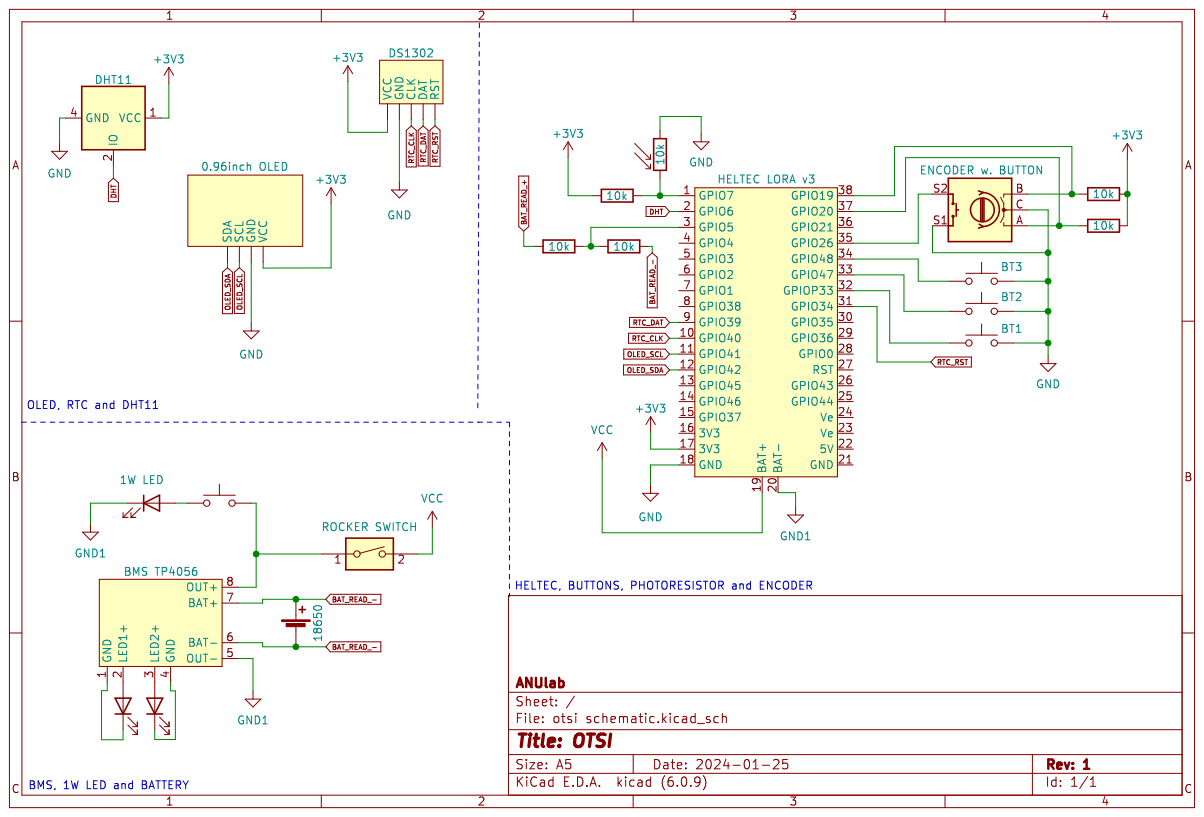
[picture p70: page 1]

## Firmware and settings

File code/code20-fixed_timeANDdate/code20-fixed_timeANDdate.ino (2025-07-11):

int main_utc = 4;
int settingsT = 0, hourPM, dayPM, monPM, yearPM, mon_NFU, day_NFU, year_NFU;
int years[] = {2024, 2028, 2032, 2036, 2040, 2044, 2048, 2052, 2056, 2060, 2064, 2068, 2072, 2076, 2080, 2084, 2088, 2092, 2096, 2100};


int hT, mT, sT, dT, mmT, yT;
String minutes_NFU = "", hours_NFU = "", seconds_NFU = "";
#include <virtuabotixRTC.h>
virtuabotixRTC myRTC(40, 39, 34);

void setup() {
  Serial.begin(9600);
  hT = 20;
  mT = 50;
  sT = 0;
  dT = 31;
  mmT = 1;
  yT = 2024;
}




void loop() {
  //********************FIXED TIME******************
  //------Fixed hours, minutes, seconds------
  //hours
  int h = hT + main_utc;
  if(h > 23){
    hours_NFU = h - 24;
    dayPM = 1;
  }
  else if(h < 0){
    hours_NFU = 24 + h;
    dayPM = -1;
  }
  else{
    hours_NFU = h;
    dayPM = 0;
  }
  //minutes
  int m = mT;
  if(m < 10){
    minutes_NFU = "";
    minutes_NFU += "0";
    minutes_NFU += String(m);
  }
  else minutes_NFU = String(m);
  //seconds
  int s = sT;
  if(s < 10){
    seconds_NFU = "";
    seconds_NFU += "0";
    seconds_NFU += String(s);
  }
  else seconds_NFU = String(s);

  //------Fixed date------
  //mon_NFU, day_NFU, year_NFU, monPM, yearPM;
  int d = dT;
  int mm = mmT;
  int y = yT;

  //day
  if(d+dayPM > 0 && d+dayPM < 29){
    day_NFU = d + dayPM;
    monPM = 0;
  }
  else if(d+dayPM == 0){
    monPM = -1;
    if(mm == 1 || mm == 2 || mm == 4 || mm == 6 || mm == 8 || mm == 9 || mm == 11) day_NFU = 31;
    else if(mm == 3){
      if(y == years[1] || y == years[2] || y == years[3] || y == years[4] || y == years[5] || y == years[0] || y == years[6] || y == years[7] || y == years[8] || y == years[9] || y == years[10]) day_NFU = 29;
      else day_NFU = 28;
    }
    else day_NFU = 30;
  }
  else if(d+dayPM == 29){
    if(y == years[1] || y == years[2] || y == years[3] || y == years[4] || y == years[5] || y == years[0] || y == years[6] || y == years[7] || y == years[8] || y == years[9] || y == years[10]){
      if(mm == 2) day_NFU = d+dayPM;
      else day_NFU = d+dayPM;
    }
    else if(y != years[1] || y != years[2] || y != years[3] || y != years[4] || y != years[5] || y != years[0] || y != years[6] || y != years[7] || y != years[8] || y != years[9] || y != years[10]){
      if(mm == 2){
        monPM = 1;
        day_NFU = 1;
      }
      else day_NFU = d+dayPM;
    } 
  }
  else if(d+dayPM == 30){
    if(y == years[1] || y == years[2] || y == years[3] || y == years[4] || y == years[5] || y == years[0] || y == years[6] || y == years[7] || y == years[8] || y == years[9] || y == years[10]){
      if(mm == 2){
        monPM = 1;
        day_NFU = 1;
      }
      else day_NFU = d+dayPM;
    }
    else day_NFU = d+dayPM;
  }
  else if(d+dayPM == 31){
    if(mm == 4 || mm == 6 || mm == 9 || mm == 11){
      monPM = 1;
      day_NFU = 1;
    } 
    else day_NFU = d+dayPM;
  }
  else if(d+dayPM == 32){
    monPM = 1;
    day_NFU = 1;
  }
  //mon
  if(mm+monPM > 0 && mm+monPM < 13){
    mon_NFU = mm+monPM;
    yearPM = 0;
  }
  else if(mm+monPM == 0){
    mon_NFU = 12;
    yearPM = -1;
  }
  else if(mm+monPM == 13){
    mon_NFU = 1;
    yearPM = 1;
  }
  //year
  year_NFU = y + yearPM;



  //debug
  Serial.print("h: ");
  Serial.print(hours_NFU);
  Serial.print("\t");
  Serial.print("m: ");
  Serial.print(minutes_NFU);
  Serial.print("\t");
  Serial.print("s: ");
  Serial.print(seconds_NFU);
  Serial.print("\t");
  Serial.print("D: ");
  Serial.print(day_NFU);
  Serial.print("\t");
  Serial.print("MM: ");
  Serial.print(mon_NFU);
  Serial.print("\t");
  Serial.print("Y: ");
  Serial.println(year_NFU);
  delay(5000);
}

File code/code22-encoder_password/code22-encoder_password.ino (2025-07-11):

//------libraries------
#include <SPI.h>
#include <Wire.h>
#include <Adafruit_GFX.h>
#include <Adafruit_SSD1306.h>
#include "images.h"
#include <virtuabotixRTC.h>
#include <Time.h>
#include "time.h"
#include "WiFi.h"
#include <dht11.h>

//------define------
#define CLK 20
#define DT 19
#define SW 26
#define BT1 48
#define BT2 47
#define BT3 33

//------Displays init------
Adafruit_SSD1306 display1(128, 64, &Wire, 21, 500000UL);
Adafruit_SSD1306 display2(128, 64, &Wire1, -1, 400000UL);

String ssid = "UPC0520860";
String password = "Ae8kdjbmaerx";
int current_screen = 0, currentStateCLK, lastStateCLK;
long lastButtonPress;

//wifi password setup
int letterIndex = 0, changePorS = 0, lenText;
char list_of_nonC_letters [] [2] = {{"a"}, {"b"}, {"c"}, {"d"}, {"e"}, {"f"}, {"g"}, {"h"}, {"i"}, {"j"}, {"k"}, {"l"}, {"m"}, {"n"}, {"o"}, {"p"}, {"q"}, {"r"}, {"s"}, {"t"}, {"u"}, {"v"}, {"w"}, {"x"}, {"y"}, {"z"}, {"0"}, {"1"}, 
{"2"}, {"3"}, {"4"}, {"5"}, {"6"}, {"7"}, {"8"}, {"9"}, {"!"}, {"@"}, {"#"}, {"$"}, {"%"}, {"^"}, {"&"}, {"*"}, {"("}, {")"}, {"."}, {","}, {":"}, {";"}, {"'"}, {'"'}, {"/"}, {"?"}, {"|"}, {"["}, {"]"}, {"{"}, {"}"}, {"<"}, {">"},};
char list_of_C_letters [] [2] = {{"A"}, {"B"}, {"C"}, {"D"}, {"E"}, {"F"}, {"G"}, {"H"}, {"I"}, {"J"}, {"K"}, {"L"}, {"M"}, {"N"}, {"O"}, {"P"}, {"Q"}, {"R"}, {"S"}, {"T"}, {"U"}, {"V"}, {"W"}, {"X"}, {"Y"}, {"Z"}, {"0"}, {"1"}, 
{"2"}, {"3"}, {"4"}, {"5"}, {"6"}, {"7"}, {"8"}, {"9"}, {"!"}, {"@"}, {"#"}, {"$"}, {"%"}, {"^"}, {"&"}, {"*"}, {"("}, {")"}, {"."}, {","}, {":"}, {";"}, {"'"}, {'"'}, {"/"}, {"?"}, {"|"}, {"["}, {"]"}, {"{"}, {"}"}, {"<"}, {">"},};
String passwordSet = "", SSIDset = "", letter = "", text = "";


void setup() {
  Serial.begin(9600);

  pinMode(CLK,INPUT);
	pinMode(DT,INPUT);
	pinMode(SW, INPUT_PULLUP);
  pinMode(BT1, INPUT_PULLUP);
  pinMode(BT2, INPUT_PULLUP);
  pinMode(BT3, INPUT_PULLUP);


  Wire1.begin(41,42);
  display2.begin(SSD1306_SWITCHCAPVCC, 0x3D);
  display2.clearDisplay();
  display2.display();
  display2.setTextSize(1);
  display2.setTextColor(WHITE); 
}

void loop() {
  //------Display init and frames------
  display2.clearDisplay();
  display2.drawBitmap(0, 0, (const unsigned char *)frameBig, 128, 64, WHITE);

  //------Insert letter to "text"------
  if(digitalRead(SW) == LOW){
    if(millis() - lastButtonPress > 50){
      text = text + letter;
      Serial.print(text);
      fix_5();
    }
    lastButtonPress = millis();
  }

  //------backspace------
  if(digitalRead(BT1) == LOW && digitalRead(BT2) == LOW){
    if(millis() - lastButtonPress > 50){
      lenText = text.length();
      text = text.substring(0, lenText-1);
      fix_5();
    } 
    lastButtonPress = millis();
  }

  //------Switch bteween password and ssid------
  if(digitalRead(BT1) == LOW){
    if(millis() - lastButtonPress > 50){
      changePorS++;
      text = "";
      if(changePorS > 1) changePorS = 0;
      fix_5();
    } 
    lastButtonPress = millis();
  }
  if(changePorS == 0) passwordSet = text;
  else if(changePorS == 1) SSIDset = text;

  //------Encoder based keyboard------
  currentStateCLK = digitalRead(CLK);
  if (currentStateCLK != lastStateCLK  && currentStateCLK == 1){
		if (digitalRead(DT) != currentStateCLK) {
      letterIndex--;
      if(letterIndex < 0) letterIndex = 60;
    }
    else {
      letterIndex++;
      if(letterIndex > 60) letterIndex = 0;
    }
    display2.setCursor(5,5);
    display2.print("letter: ");
    display2.setCursor(47,5);
    //Capital letter or not
    if(digitalRead(BT2) == LOW){
      if(millis() - lastButtonPress > 50){
        display2.print(list_of_C_letters[letterIndex]);
        letter = list_of_C_letters[letterIndex];
      }
      lastButtonPress = millis();
    }
    else{
      display2.print(list_of_nonC_letters[letterIndex]);
      letter = list_of_nonC_letters[letterIndex];
    }
    //print written text on a screen
    display2.setCursor(5, 15);
    display2.print("PW: ");
    display2.setCursor(24,15);
    display2.print(passwordSet);
    display2.setCursor(5,25);
    display2.print("SSID:");
    display2.setCursor(37,25);
    display2.print(SSIDset);

    display2.display(); 
  }
  lastStateCLK = currentStateCLK;
  delay(1);  
  
  //------return button------
  if(digitalRead(BT3) == LOW){
    if(millis() - lastButtonPress > 50) {
      //to add
      password = passwordSet;
      ssid = SSIDset;
      Serial.println(password);
      Serial.println(ssid);
	  } 
  lastButtonPress = millis();
  }
}

void fix_5(){
  currentStateCLK = 1;
  lastStateCLK = 0;
  letterIndex--;
}

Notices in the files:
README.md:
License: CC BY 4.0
